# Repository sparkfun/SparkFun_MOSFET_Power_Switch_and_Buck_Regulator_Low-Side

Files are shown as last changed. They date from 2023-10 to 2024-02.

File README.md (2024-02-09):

SparkFun MOSFET Power Switch and Buck Regulator (Low-Side)
========================================

SparkFun MOSFET Power Switch and Buck Regulator (Low-Side) (https://www.sparkfun.com/products/23979)

[*SparkFun MOSFET Power Switch and Buck Regulator (Low-Side) (COM-23979)*](https://www.sparkfun.com/products/23979)

Does your microcontroller need to control a high-voltage item, like a 12V LED strip, while also needing to be powered? Do you want to avoid having multiple power adapters and microcontrollers for your project? The MOSFET Power Switch and Buck Regulator (Low-Side) is one product we needed at SparkFun, so we figured other folks might have the same problem. Power the board with up to 12V and control up to 10A, all while providing a sweet 3.3V to your control board.

The SparkFun MOSFET Power Switch and Buck Regulator (Low-Side) combines two circuits into one board: an LMR14203 buck regulator configured to output 3.3V and an N-channel MOSFET (PSMN7R0-100BS) configured as a low-side switch. A flyback diode is also on the load side for devices with back EMF! Simply pull the CTL pin low to activate the load.

Various connectors (barrel jack, female header, and poke-home) are provided to connect a power supply to a microcontroller of your choice (Arduino, micro-bit, Raspberry Pi’s microcontroller) and load them together. VCC, 3.3V, CTL, and GND are also broken out through 0.1" spaced PTHs for those who prefer to solder. Two LEDs (PWR_LED and ON_LED) indicate when there is 3.3V and whenever power is applied to the load. Jumpers are included on the back to disable the LEDs. A MEAS PTH jumper is also included for those interested in precisely measuring the current consumption of the system.

_**Note:** While the MOSFET is rated to 100A/100V, we don't recommend you go much above 10A as the PCB polygon pours and traces become the limiter._

Repository Contents
-------------------

* **.github/workflows** -  YAML files used for GitHub Actions and GitHub Pages/mkdocs
* * **/Firmware** - Basic example code to control a load with the MOSFET Power Switch and BUck Regulator
* **/Hardware** - Eagle design files (.brd, .sch)
  * **/Production** - Production panel files (.brd)
* **/docs** - Online documentation files for GitHub Pages and mkdocs
  * **/assets** - Folder containing all the file assets used for product documentation
    * **/board_files** - Copy of design files used for product documentation
    * **/component_documentation** - Datasheets and manuals for hardware components
    * **/img** - Images for product documentation
  * **/github** - Files stating how to contribute and filing issues for product
  * **/javascript** - Folder containing custom javascript used for product documentation
  * **/stylesheet** - Folder containing CSS files used forproduct documentation
* **/overrides** - Customization files used for product documentation
  * **/.icons** - Icons used for product documentation
  * **./partials** - Used for product documentation

Documentation
--------------

* **[Fritzing Part](https://github.com/sparkfun/Fritzing_Parts/blob/main/products/23979_sfe_n-channel_mosfet_power_switch_buck_regulator_low-side_transistor.fzpz)**
* **[Hookup Guide](https://docs.sparkfun.com/SparkFun_MOSFET_Power_Switch_and_Buck_Regulator_Low-Side)** - Basic hookup guide for the MOSFET Power Switch and Buck Regulator (Low-Side).

Product Versions
----------------

* [COM-23979](https://www.sparkfun.com/products/23979) - Initial SparkFun release, v1.1
* [SPX-19799](https://www.sparkfun.com/products/19799) - SparkX version

Version History
---------------
* v1.1 - Initial release

License Information
-------------------

This product is _**open source**_! 

Please review the LICENSE.md file for license information. 

If you have any questions or concerns on licensing, please contact technical support on our [SparkFun forums](https://forum.sparkfun.com/viewforum.php?f=152).

Distributed as-is; no warranty is given.

- Your friends at SparkFun.

_<COLLABORATION CREDIT>_

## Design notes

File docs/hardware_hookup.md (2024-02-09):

In this section, we'll go over how to connect the MOSFET Power Switch to your system.

## Upload Code to the Microcontroller

When uploading code to the IoT RedBoard - ESP32, we will connect a USB C cable. When powering the load, we will want to disconnect the USB cable to avoid conflicting voltages.

<div style="text-align: center;">
  <table>
    <tr style="vertical-align:middle;">
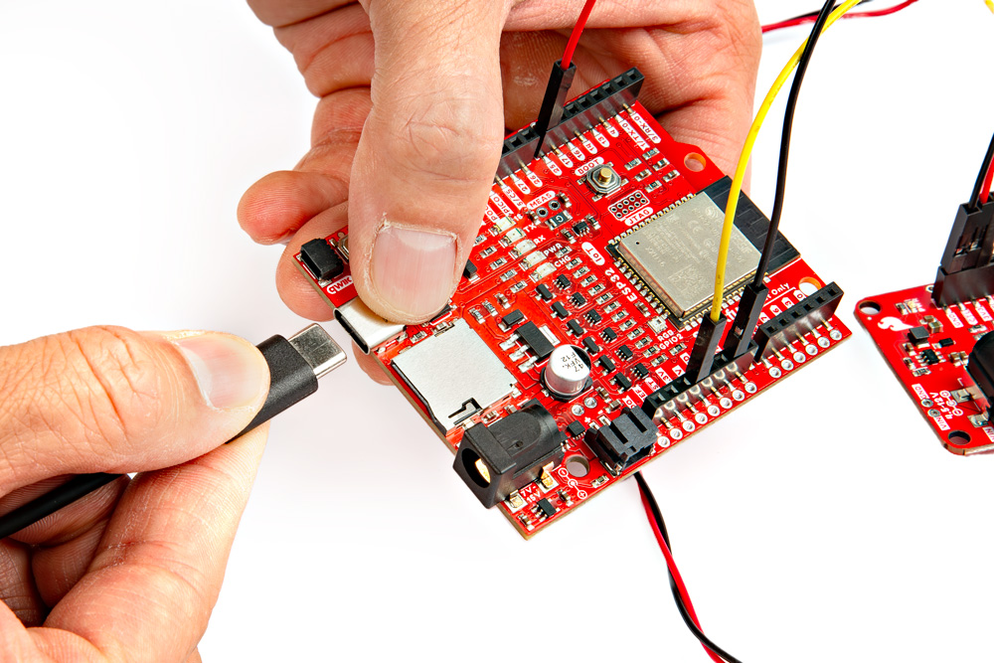
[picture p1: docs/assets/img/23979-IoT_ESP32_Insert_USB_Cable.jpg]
USB Cable Out of USB Connector
     <td style="text-align: center; vertical-align: middle;"></td>
  </table>
</div>

!!! tip
     If necessary, you can disconnect the 3.3V jumper wire connecting the MOSFET Power Switch and Buck Regulator to the IoT RedBoard - ESP32. That way you can power the load with the barrel jack while also debugging code when the USB cable is connected to the IoT RedBoard - ESP32.

### Control

!!! note
    The tutorial focuses on using a microcontroller with Arduino. However, if your microcontroller has a digital or PWM, you can also control the N-channel MOSFET controller as well! You can also use this using a micro:bit with MakeCode or Raspberry Pi's RP2040 microcontroller with MicroPython!

For prototyping or connecting to the control side, we recommend using a 3.3V development board with header pins already soldered to the board. In this case, we used the IoT RedBoard - ESP32. Depending on how you are controlling the load, you may need a digital or PWM pin. Don't forget to connect power and ground. In this case, we will use 3.3V from the output of the buck regulator. Of course, you could also connect the microcontroller or additional devices to the VCC pin as an alternative. Just make sure to choose one when powering your microcontroller or any additional peripheral device.

<div style="text-align: center;">
    <table>
        <tr>
            <th style="text-align: center; border: solid 1px #cccccc;">MOSFET Power Switch
            </th>
            <th style="text-align: center; border: solid 1px #cccccc;">IoT RedBoard - ESP32
            </th>
        </tr>
        <tr>
            <td style="text-align: center; border: solid 1px #cccccc;" bgcolor="#f2dede"><font color="#000000">3V3</font>
            </td>
            <td style="text-align: center; border: solid 1px #cccccc;" bgcolor="#f2dede"><font color="#000000">3.3V</font>
            </td>
        </tr>
        <tr>
            <td style="text-align: center; border: solid 1px #cccccc;" bgcolor="#DDDDDD"><font color="#000000">GND</font>
            </td>
            <td style="text-align: center; border: solid 1px #cccccc;" bgcolor="#DDDDDD"><font color="#000000">GND</font>
            </td>
        </tr>
        <tr>
            <td style="text-align: center; border: solid 1px #cccccc;" bgcolor="#cce5ff"><font color="#000000"><span style="text-decoration:overline">CTL</span></font>
            </td>
            <td style="text-align: center; border: solid 1px #cccccc;" bgcolor="#cce5ff"><font color="#000000">D25</font>
            </td>
        </tr>
    </table>
</div>

Below is a circuit diagram with the MOSFET Power Switch and Buck Regulator Break connecting to the IoT RedBoard - ESP32. Most of the examples will follow this pin connection to control the load. However, there are a few examples that will include additional circuits and a different pin for the control.

<div style="text-align: center;">
  <table>
    <tr style="vertical-align:middle;">
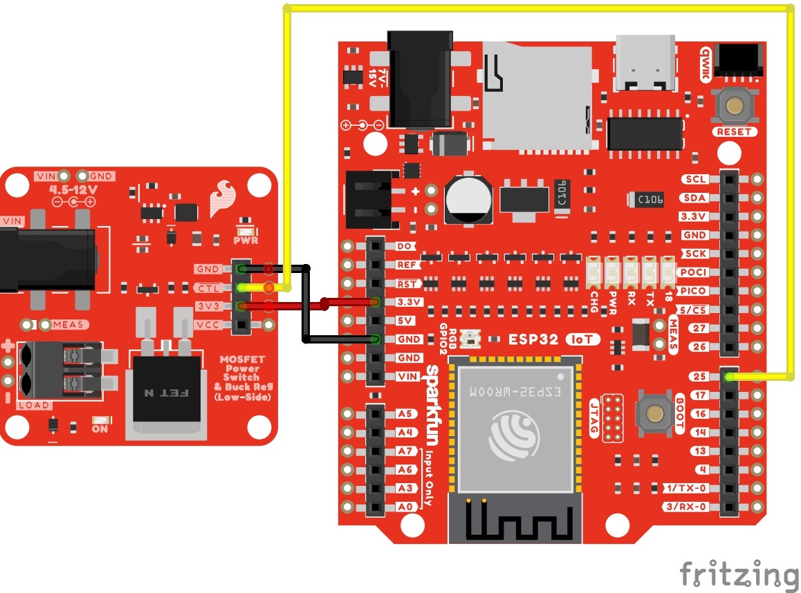
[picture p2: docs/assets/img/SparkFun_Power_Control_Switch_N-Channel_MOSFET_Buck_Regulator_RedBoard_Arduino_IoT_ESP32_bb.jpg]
Power and Control Pin Connected to RedBoard IoT Development Board
     <td style="text-align: center; vertical-align: middle;"></td>
    </tr>
  </table>
</div>

!!! warning
    When powering and programming your Arduino, make sure to disconnect power between the MOSFET Power Switch and Arduino to avoid conflicting voltages. Of course you could use a [Schottky diode for protection](https://learn.sparkfun.com/tutorials/diodes#diode-applications). The caveat is that you will just have a slight voltage drop.

### Load

Connect a high voltage device of your choice (e.g. DC motor, solenoid, 12V LED) to the load side (VCC to &plus; and GND to &minus;). You will need a ball point pen to push down on each poke-home connector's tab. A [mini screwdriver](https://www.sparkfun.com/products/9146) (Phillips or flat head) will also work as well.  As you are pressing down on the tab, insert a [stripped wire](https://learn.sparkfun.com/tutorials/working-with-wire/how-to-strip-a-wire) or jumper wire pin into the socket. Repeat for the other connection.

<div style="text-align: center;">
  <table>
    <tr style="vertical-align:middle;">
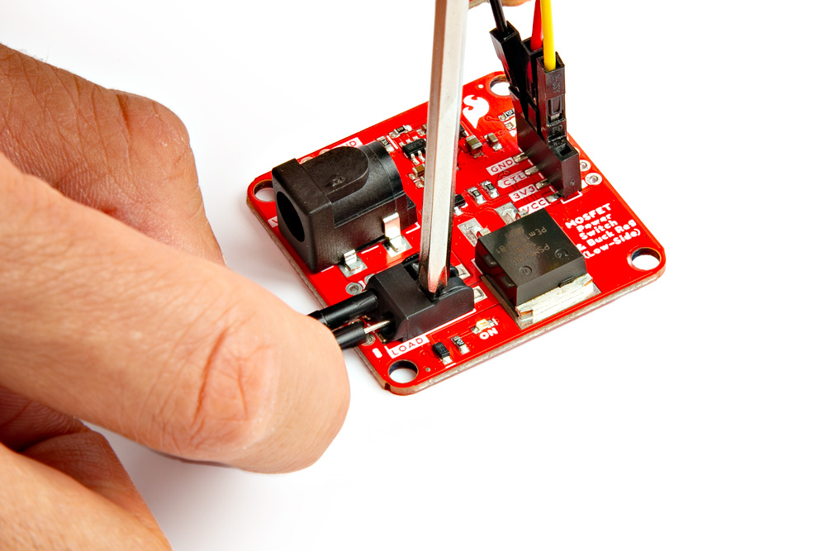
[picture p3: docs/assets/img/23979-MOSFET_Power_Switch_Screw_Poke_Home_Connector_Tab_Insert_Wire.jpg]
Mini Screwdriver Pushing Down on Poke-Home Connector Tab and Wire Being Inserted
     <td style="text-align: center; vertical-align: middle;"></td>
    </tr>
  </table>
</div>

Below are a few examples. The squirrel cage blower we just inserted the Poke-Home conenctor since the wires were stripped. For the latching solenoid, we used M/M jumper wires between the 2-pin connector and the Poke-Home connector. We used part of a 12V LED strip rather than a full strip.

<div style="text-align: center;">
  <table>
    <tr style="vertical-align:middle;">
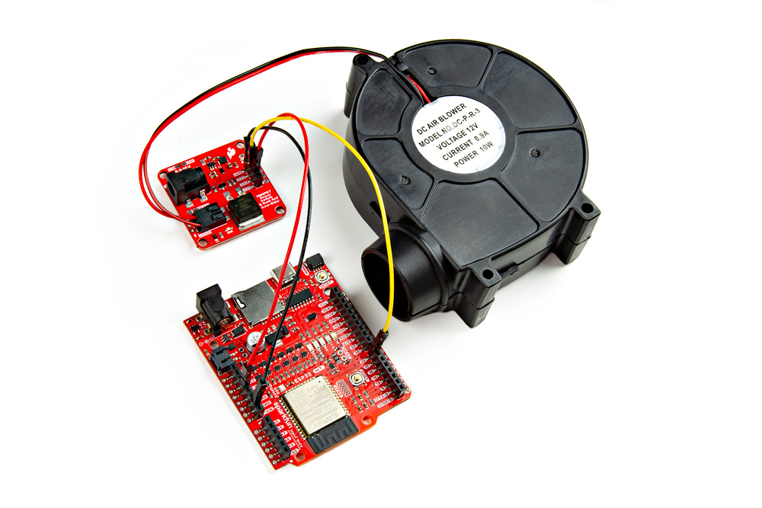
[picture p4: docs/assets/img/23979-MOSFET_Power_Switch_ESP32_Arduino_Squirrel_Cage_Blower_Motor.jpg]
DC Motor to MOSFET Power Switch
     <td style="text-align: center; vertical-align: middle;"></td>
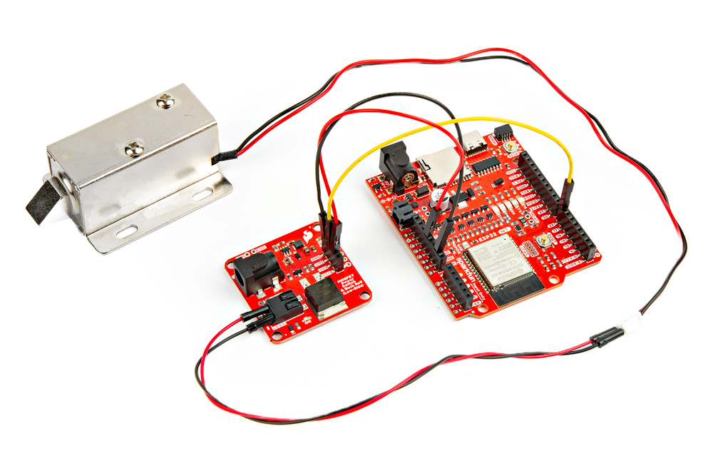
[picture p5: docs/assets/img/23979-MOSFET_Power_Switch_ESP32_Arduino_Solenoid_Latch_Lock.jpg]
Solenoid to MOSFET Power Switch
     <td style="text-align: center; vertical-align: middle;"></td>
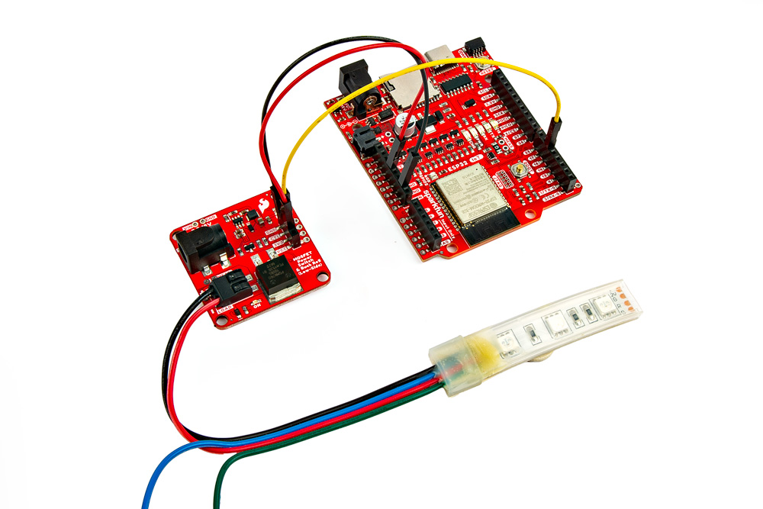
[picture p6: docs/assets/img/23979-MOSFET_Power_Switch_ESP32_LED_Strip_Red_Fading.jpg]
12V LED Strip to MOSFET Power Switch
     <td style="text-align: center; vertical-align: middle;"></td>
    </tr>
  </table>
</div>

!!! tip
    Worried about the M/M jumper wire's pins when inserting the Poke-Home connector? There are other [M/M jumper wires available](https://www.sparkfun.com/products/11026). These are lower cost and  so you do not have to worry about damaging your premium jumper wires. These were used with the latching solenoid's 2-pin connector.

### Input Voltage

Grab a compatible wall adapter that is within the recommended voltage range for your project. Make sure that the barrel jack's output is a center-positive. Then insert it into the barrel jack connector.

<div style="text-align: center;">
  <table>
    <tr style="vertical-align:middle;">
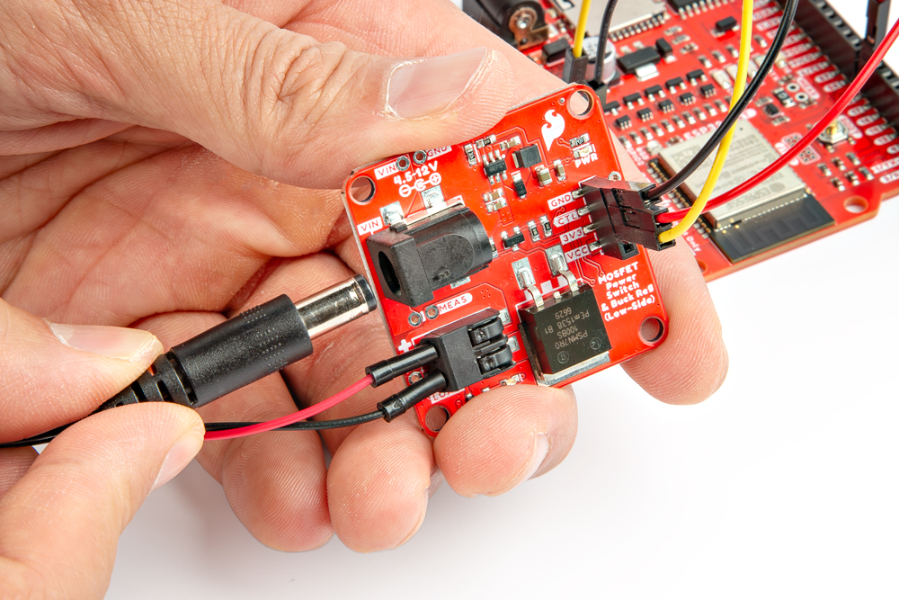
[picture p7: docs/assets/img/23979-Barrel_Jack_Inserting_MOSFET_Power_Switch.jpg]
Wall Adapter Connected to Barrel Jack
     <td style="text-align: center; vertical-align: middle;"></td>
    </tr>
  </table>
</div>

### Connecting to the PTHs

For users that prefer to use the PTHs, we recommending soldering to the connection. You can choose between a combination of [header pins and jumper wires](https://learn.sparkfun.com/tutorials/how-to-solder-through-hole-soldering/all), or [stripping wire and soldering the wire](https://learn.sparkfun.com/tutorials/working-with-wire/all) directly to the board.

<div class="grid cards hide col-4" markdown>

-   <a href="https://learn.sparkfun.com/tutorials/how-to-solder-through-hole-soldering/all">
      <figure markdown>
        How to Solder: Through Hole Soldering
      </figure>
    </a>

    ---

    <a href="https://learn.sparkfun.com/tutorials/how-to-solder-through-hole-soldering/all">
      <b>How to Solder: Through Hole Soldering</b>
    </a>
<!-- ----------WHITE SPACE BETWEEN GRID CARDS---------- -->
-   <a href="https://learn.sparkfun.com/tutorials/working-with-wire/all">
      <figure markdown>
        Working with Wire
      </figure>
    </a>

    ---

    <a href="https://learn.sparkfun.com/tutorials/working-with-wire/all">
      <b>Working with Wire</b>
    </a>
<!-- ----------WHITE SPACE BETWEEN GRID CARDS---------- -->
</div>

!!! tip
    The PTHs are connected to large polygon pours and traces. You may need a larger soldering iron tip, increase the soldering station's temperature, some flux, or leave the soldering tip a little longer in order for the solder to flow better.

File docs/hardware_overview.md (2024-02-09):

In this section, we will highlight the features of the N-channel MOSFET Power Switch and Buck Regulator (Low-Side). For more information about the LMR14203 3.3V buck regulator or PSMN7R0-100BS N-channel MOSFET, make sure to check out the datasheets that are linked in the [Resources section](../resources).

<div style="text-align: center;">
  <table>
    <tr style="vertical-align:middle;">
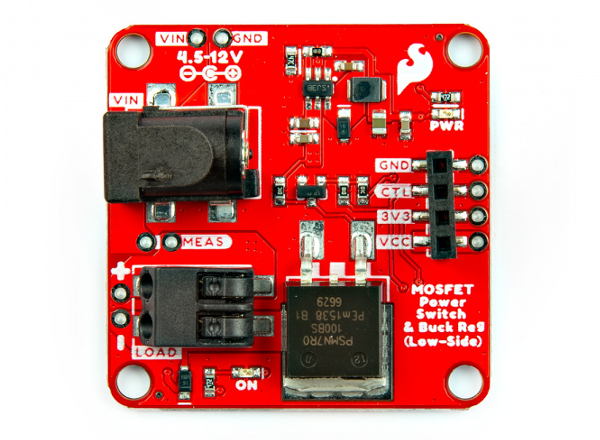
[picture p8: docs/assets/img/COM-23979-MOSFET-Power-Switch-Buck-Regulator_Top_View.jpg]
MOSFET Power Switch Top
     <td style="text-align: center; vertical-align: middle;"></td>
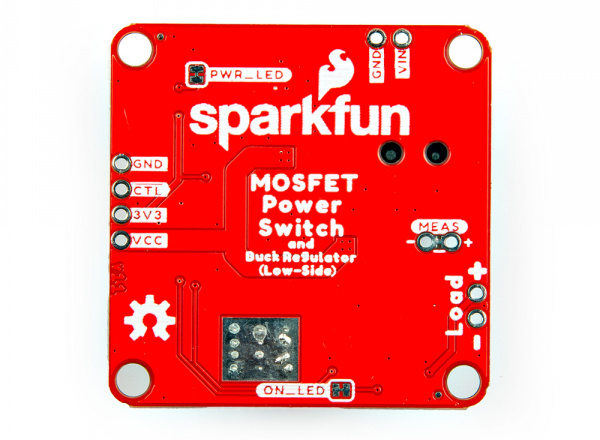
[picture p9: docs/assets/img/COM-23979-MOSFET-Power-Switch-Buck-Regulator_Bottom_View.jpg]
MOSFET Power Switch Bottom
     <td style="text-align: center; vertical-align: middle;"></td>
    </tr>
    <tr style="vertical-align:middle;">
     <td style="text-align: center; vertical-align: middle;"><i>Top View</i>
     </td>
     <td style="text-align: center; vertical-align: middle;"><i>Bottom View</i>
     </td>
    </tr>
  </table>
</div>

### N-Channel MOSFET

The N-channel MOSFET is configured as a low-side switch. On the back of the board, there is a ground plane to aid in heat dissipation. At 12V, 3A the board stays cool (40 &degC;) under a continuous load. At 12V, 8.5A with shorter bursts of current (i.e. 5-10 seconds per burst, max current), the board gets toasty (80&degC;). You will want to avoid touching the board since it will burn your finger.

<div style="text-align: center;">
  <table>
    <tr style="vertical-align:middle;">
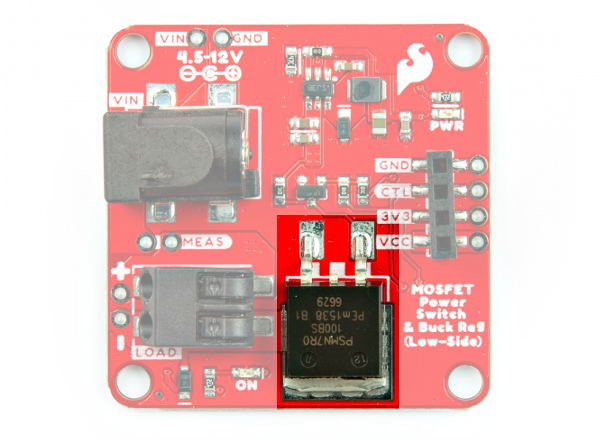
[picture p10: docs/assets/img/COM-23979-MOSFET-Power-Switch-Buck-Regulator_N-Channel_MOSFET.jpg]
N-Channel MOSFET Highlighted
     <td style="text-align: center; vertical-align: middle;"></td>
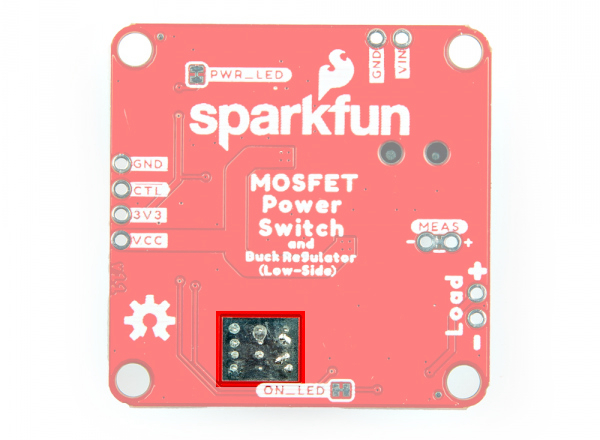
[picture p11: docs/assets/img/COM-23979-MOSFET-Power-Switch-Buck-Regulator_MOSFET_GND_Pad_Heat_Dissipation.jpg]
Ground Plane Under MOSFET Highlighted for Heat Dissipation
     <td style="text-align: center; vertical-align: middle;"></td>
    </tr>
    <tr style="vertical-align:middle;">
     <td style="text-align: center; vertical-align: middle;"><i>N-Channel MOSFET</i>
     </td>
     <td style="text-align: center; vertical-align: middle;"><i>Ground Plane Under MOSFET for Heat Dissipation</i>
     </td>
    </tr>
  </table>
</div>

### Input Voltage

There are two options to connect to the input voltage:

* **Barrel Jack** &mdash; For users with a wall adapter, you could use a 5.5mm x 2.1mm center positive, barrel jack with the recommended input voltage. This is for users that want to easily connect the power supply without the need to solder. Make sure to check the specifications of your wall adapter before connecting since some power supplies have a different polarity.
* **PTHs** &mdash; There is also a pair of pads beside the barrel jack to connect to the input voltage (**VIN**) and ground (**GND**). The PTHs are for users that want a more permanent connection and require a smaller profile by soldering wires directly to the PTH. We recommend connecting power from your power supply to this VIN PTH rather than the one by the 1x4 header. The polygon pours connected to the PTH are thicker and can handle the power as opposed to the VCC pin by the 1x4 header.

These connections are broken out as follows:

* **VIN** &mdash; The recommended input voltage is between **4.5V** and **12V**.
* **GND** &mdash; Common ground or 0V.

<div style="text-align: center;">
  <table>
    <tr style="vertical-align:middle;">
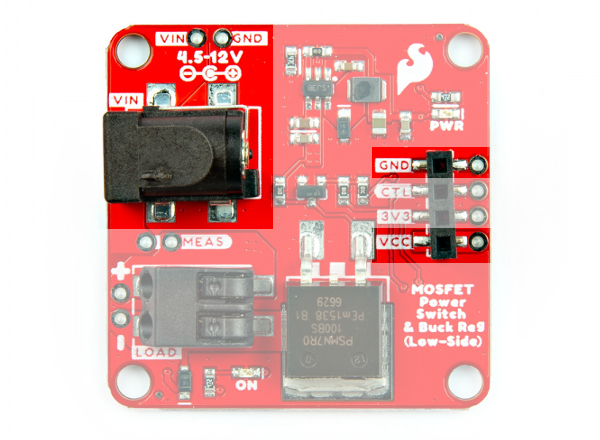
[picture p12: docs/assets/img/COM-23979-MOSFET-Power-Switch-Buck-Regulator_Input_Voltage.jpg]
Input Voltage Options Highlighted
     <td style="text-align: center; vertical-align: middle;"></td>
    </tr>
    <tr style="vertical-align:middle;">
     <td style="text-align: center; vertical-align: middle;"><i>Input Voltage Options Highlighted
         </i>
     </td>
    </tr>
  </table>
</div>

### 3.3V Regulator Output Voltage

Voltage from the input is brought down to 3.3V/300mA with the buck regulator. This is intended to connect to a microcontroller's 3.3V pin using either the 1x4 header and the PTHs.

<div style="text-align: center;">
  <table>
    <tr style="vertical-align:middle;">
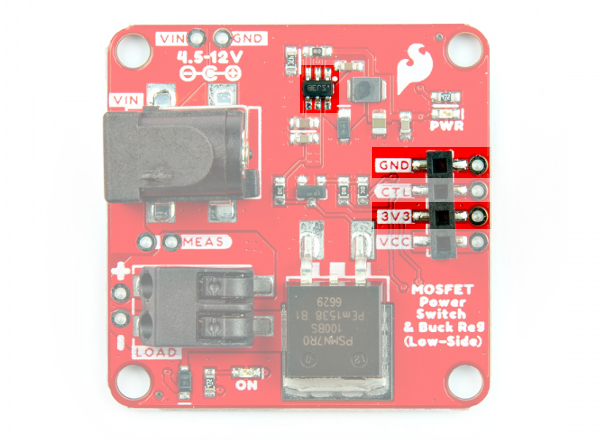
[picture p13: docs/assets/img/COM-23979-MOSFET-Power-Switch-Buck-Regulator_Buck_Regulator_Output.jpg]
     <td style="text-align: center; vertical-align: middle;"></td>
    </tr>
    <tr style="vertical-align:middle;">
     <td style="text-align: center; vertical-align: middle;"><i>Output Voltage Highlighted
         </i>
     </td>
    </tr>
  </table>
</div>

### 1x4 Header Connections

On the side of the board, there are two options to connect to ground, control pin, output 3.3V voltage, and input voltage,

* **1x4 female header** &mdash; Users that have jumper wires with male pins can easily connect to the female headers.
* **PTHs** &mdash; For users that require a more secure connection like the input voltage side, you can also solder to the PTHs as well. As explained earlier, the traces connecting to the VCC on this side is not as big as the one by VIN by the barrel jack.

These connections are broken out as follows:

* **GND** &mdash; Common ground or 0V.
* **<span style="text-decoration:overline">CTL</span>** &mdash; Short for control, this pin is connected to the N-channel MOSFET's gate pin and it is active low. There is a [pull-up resistor](https://learn.sparkfun.com/tutorials/pull-up-resistors/all) connected to this pin. Users can connect to a jumper wire from this pin to GND to turn on the MOSFET and provide power to the load. Of course, this board was designed to connect to a microcontroller so it can be connected to a digital or PWM pin. Toggling the control pin with the digital pin will turn on and off MOSFET. Using a PWM pin will give you more flexibility to turn on, off, or partially on the load.  
* **3V3** &mdash; 3.3V output from the buck regulator. This is intended to connect to a microcontroller's 3.3V pin.
* **VCC** &mdash; This pin is connected to the MEAS jumper and VIN. The trace connecting to the pin on the control side is smaller than the polygon pour for VIN. Users can also connect the microcontroller's input voltage to this pin as an alternative to using the 3V3 if their system requires. Just make sure to choose either the 3V3 or VCC to power the microcontroller. Of course, users can also power additional devices on this pin as well.

<div style="text-align: center;">
  <table>
    <tr style="vertical-align:middle;">
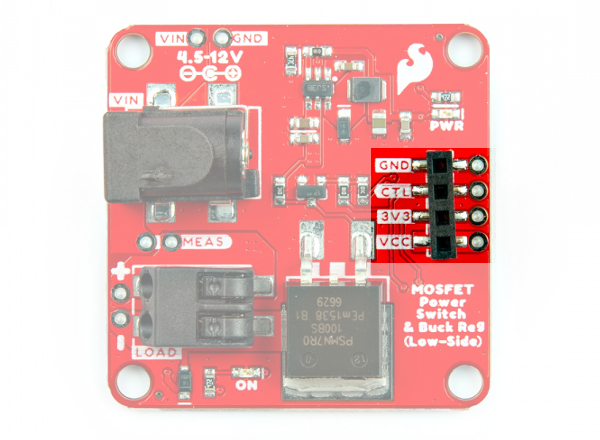
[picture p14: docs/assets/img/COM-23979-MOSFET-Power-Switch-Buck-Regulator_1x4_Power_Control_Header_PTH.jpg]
Control Side Highlighted
     <td style="text-align: center; vertical-align: middle;"></td>
    </tr>
    <tr style="vertical-align:middle;">
     <td style="text-align: center; vertical-align: middle;"><i>1x4 Header Highlighted
         </i>
     </td>
    </tr>
  </table>
</div>

### Load Side

There are two options to connect to the output load side.

* **Poke-Home Connectors** &mdash; For users that have a stripped wire or jumper wire pins, you can use a ballpoint pen to press down on the tab of the connector to insert a stripped wire or pin into the connector. You can also use a mini screwdriver (Phillips or flat head)
* **PTHs** &mdash; For users that want a permanent connection, you can solder your load directly to the PTHs.

The N-channel MOSFET is configured as a low-side switch: the load is connected to the N-channel MOSFET's drain pin, while the source is connected to ground

The load side connections are broken out as follows:

* **VCC** (or &plus;) &mdash; This pin is for connecting the load's input voltage to the VCC pin.
* **LOAD** (or &minus;) &mdash; This pin is intended for connecting the load's ground to the LOAD pin.

<div style="text-align: center;">
  <table>
    <tr style="vertical-align:middle;">
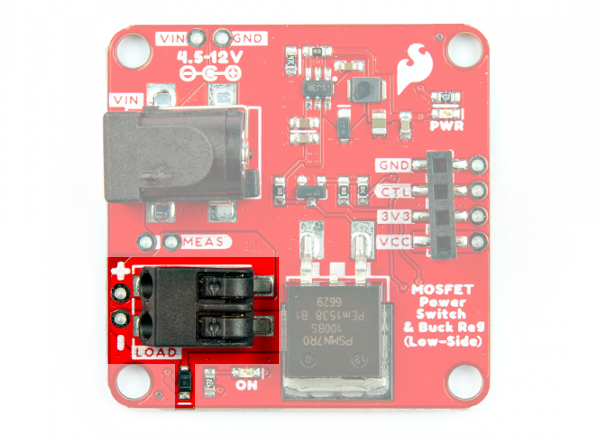
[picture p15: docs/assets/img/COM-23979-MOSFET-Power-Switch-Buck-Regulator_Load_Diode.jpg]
Load Side Highlighted
     <td style="text-align: center; vertical-align: middle;"></td>
    </tr>
    <tr style="vertical-align:middle;">
     <td style="text-align: center; vertical-align: middle;"><i>Load Side Highlighted
         </i>
     </td>
    </tr>
  </table>
</div>

!!! note
    There is also a flyback diode connected to the load side! This component is for loads with motors. When the motor is spinning and suddenly turned off, the magnetic field inside it collapses, generating a voltage spike. This can damage the transistor. These voltage spikes can also happen with solenoids. The image below (taken from [Pete](https://github.com/lewispg228)'s camera!) shows an [oscilloscope](https://learn.sparkfun.com/tutorials/how-to-use-an-oscilloscope/all) measuring the nasty voltage spike as soon as the 12V latching solenoid (without a flyback diode) is turned off.

    <div style="text-align: center;">
      <table>
        <tr style="vertical-align:middle;">
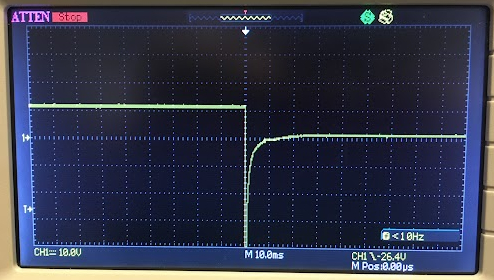
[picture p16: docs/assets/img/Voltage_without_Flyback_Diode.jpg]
Voltage without Flyback Diode
         <td style="text-align: center; vertical-align: middle;"></td>
        </tr>
        <tr style="vertical-align:middle;">
         <td style="text-align: center; vertical-align: middle;"><i>Voltage without Flyback Diode
             </i>
         </td>
        </tr>
      </table>
    </div>

    To prevent voltage spikes, we use a "[flyback diode](https://learn.sparkfun.com/tutorials/diodes#diode-applications)," which suppresses the voltage spike. As seen below the voltage is not as dangerous for our N-channel MOSFET.

    <div style="text-align: center;">
      <table>
        <tr style="vertical-align:middle;">
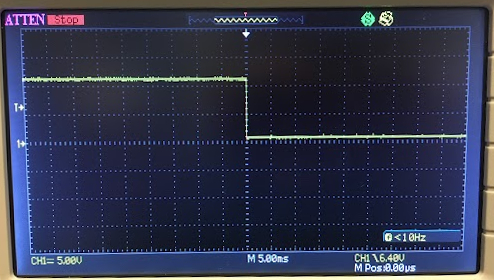
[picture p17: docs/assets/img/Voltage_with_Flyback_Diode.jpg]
Voltage without Flyback Diode
         <td style="text-align: center; vertical-align: middle;"></td>
        </tr>
        <tr style="vertical-align:middle;">
         <td style="text-align: center; vertical-align: middle;"><i>Voltage with Flyback Diode
             </i>
         </td>
        </tr>
      </table>
    </div>

### LEDs

There are two LEDs on the board.

* **PWR** &mdash; The power LED lights up when there is power on the output of the 3.3V buck regulator. This LED can be disabled by cutting the trace on the **PWR_LED** jumper.
* **ON** &mdash; The ON LED lights up when the control pin is pulled low indicating that there is power applied to the load. This LED can be disabled by cutting the trace on the **ON_LED** jumper.

<div style="text-align: center;">
  <table>
    <tr style="vertical-align:middle;">
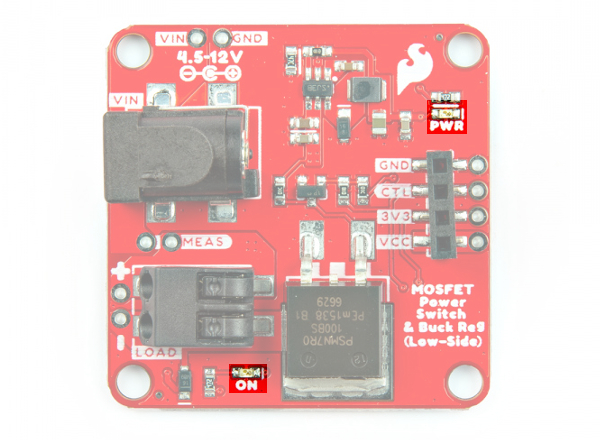
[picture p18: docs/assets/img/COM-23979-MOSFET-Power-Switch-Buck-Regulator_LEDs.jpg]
LEDs Highlighted
     <td style="text-align: center; vertical-align: middle;">
     </td>
    </tr>
    <tr style="vertical-align:middle;">
     <td style="text-align: center; vertical-align: middle;"><i>LEDs Highlighted
         </i>
     </td>
    </tr>
  </table>
</div>

### Jumpers

There are a few jumper pads available on the bottom of the board. For more information on modifying the jumpers, check out our [tutorial on working with jumper pads and PCB traces](https://learn.sparkfun.com/tutorials/how-to-work-with-jumper-pads-and-pcb-traces).

* **PWR_LED** &mdash; By default, this jumper is closed. This is connected to the **PWR** LED and indicates when there is power. Cut this trace to disable the power LED that is connected to 3.3V.
* **MEAS** &mdash; To enable measurements and determine how much current your system is pulling, we've added a NC (normally closed) jumper between the two MEAS PTH pins. By cutting this jumper, the voltage connecting to the 3.3V voltage regulator's input is interrupted. Soldering in male jumper pins or wires into the accompanying holes will give you the ability to insert a current meter and precisely monitor how much current your application is consuming.
* **ON_LED** &mdash; By default, this jumper is closed. This is connected to the **ON** LED. This LED indicates when the control pin is pulled low and when there is power applied to the load. Cut this trace to disable the **ON** LED that is connected to the control pin.

<div style="text-align: center;">
  <table>
    <tr style="vertical-align:middle;">
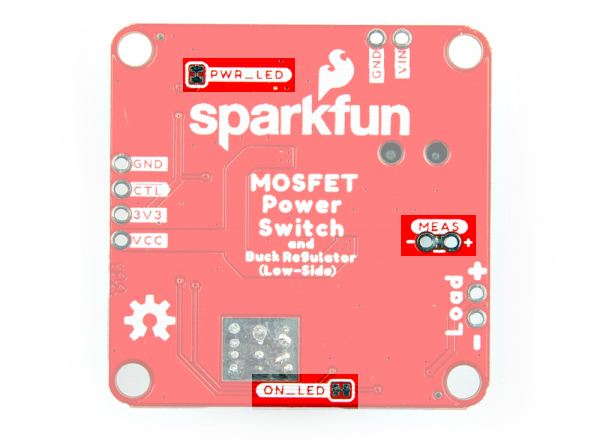
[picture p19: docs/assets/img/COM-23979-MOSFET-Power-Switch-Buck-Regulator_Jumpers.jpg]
Jumpers Highlighted
     <td style="text-align: center; vertical-align: middle;"></td>
    </tr>
    <tr style="vertical-align:middle;">
     <td style="text-align: center; vertical-align: middle;"><i>Jumpers Highlighted
         </i>
     </td>
    </tr>
  </table>
</div>

### Board Dimensions

The board is 1.50" x 1.50" (38.1mm x 38.1mm), which is slightly bigger than a typical 1.0"x1.0" Qwiic sized board. There are 4x mounting holes by each corner of the board.

<div style="text-align: center;">
  <table>
    <tr style="vertical-align:middle;">
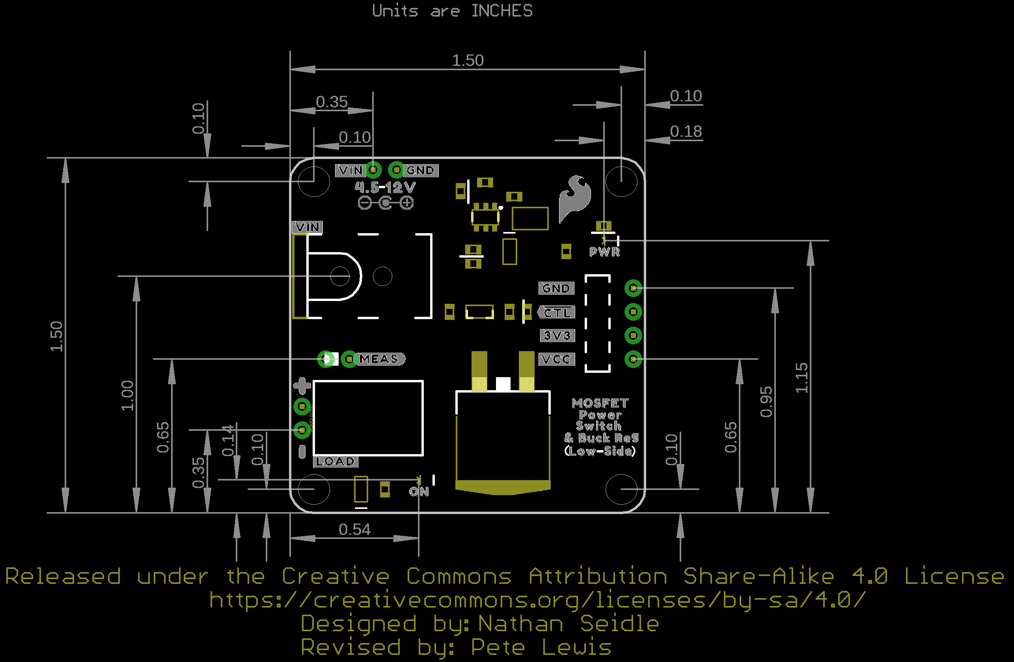
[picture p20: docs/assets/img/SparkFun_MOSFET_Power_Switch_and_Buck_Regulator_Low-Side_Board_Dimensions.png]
Board Dimensions
     <td style="text-align: center; vertical-align: middle;"></td>
    </tr>
    <tr style="vertical-align:middle;">
     <td style="text-align: center; vertical-align: middle;"><i>Board Dimensions
         </i>
     </td>
    </tr>
  </table>
</div>

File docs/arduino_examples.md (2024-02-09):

!!! arduino
    This example assumes you are using the latest version of the Arduino IDE on your desktop. If this is your first time using the Arduino IDE or board add-on, please review the following tutorials.

    - [Installing the Arduino IDE](https://learn.sparkfun.com/tutorials/installing-arduino-ide)
    - [Installing Board Definitions in the Arduino IDE](https://learn.sparkfun.com/tutorials/installing-board-definitions-in-the-arduino-ide)

    If you've never connected an CH340 device to your computer before, you may need to install drivers for the USB-to-serial converter. Check out our section on "[How to Install CH340 Drivers](https://learn.sparkfun.com/tutorials/sparkfun-serial-basic-ch340c-hookup-guide#drivers-if-you-need-them)" for help with the installation.

You will need either a microcontroller's digital or PWM pin to control the N-channel MOSFET Power Switch. Let's check out a few of the examples below to get started!

### Example 1: Switching a Load

In this example, we will turn on and off a load using the N-channel MOSFET every few seconds. The load can be a solenoid, DC motor, or a 12V LED.

#### Parts Needed

Grab the following quantities of each part listed to build this circuit:

* 1x [SparkFun IoT RedBoard - ESP32 Development Board](https://www.sparkfun.com/products/19177)
* 1x [USB-C Cable](https://www.sparkfun.com/products/15092)
* 3x [SparkFun MOSFET Power Switch and Buck Regulator (Low-Side)](https://www.sparkfun.com/products/23979)
* 1x [SparkFun Mini Screwdriver](https://www.sparkfun.com/products/9146)
* 3x [M/M Jumper Wires](https://www.sparkfun.com/products/8431)
* 1x [Squirrel Cage Blower (12V)](https://www.sparkfun.com/products/11270)
* 1x Ping Pong Ball
* 1x [12V Wall Adapter Power Supply](https://www.sparkfun.com/products/15313)

#### Hardware Hookup

You will need to connect everything as explained earlier. For this particular example, we will use a squirrel cage blower with a motor as shown in the circuit diagram below. Of course, we are using a generic motor in the circuit diagram to represent the squirrel cage blower.

<div style="text-align: center;">
  <table>
    <tr style="vertical-align:middle;">
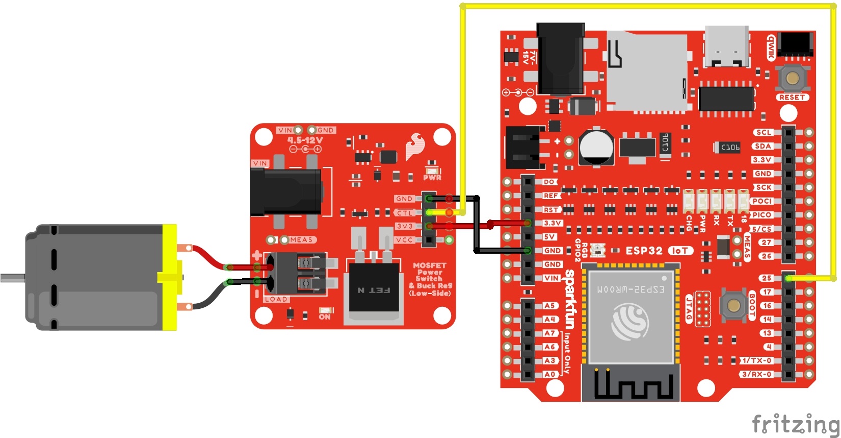
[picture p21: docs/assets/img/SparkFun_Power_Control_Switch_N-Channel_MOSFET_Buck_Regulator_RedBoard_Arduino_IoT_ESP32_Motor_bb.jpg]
DC Motor to MOSFET Power Switch
     <td style="text-align: center; vertical-align: middle;"></td>
    </tr>
  </table>
</div>

Your setup should look similar to the image below without the power supply.

<div style="text-align: center;">
  <table>
    <tr style="vertical-align:middle;">
     <td style="text-align: center; vertical-align: middle;"><a href="../assets/img/23979-MOSFET_Power_Switch_ESP32_Arduino_Squirrel_Cage_Blower_Motor.jpg">DC Motor to MOSFET Power Switch</a></td>
    </tr>
  </table>
</div>

#### Upload Code

To upload code, insert the USB cable into the IoT RedBoard - ESP32.

!!! note
    This example is similar to the built-in Arduino example. From the menu, select the following: **File** > **Examples** > **01.Basics** > **Blink**. You will need to modify the macro (`LED_BUILTIN`) with a digital pin for your microcontroller. Note that the logic is reversed due to the transistor.

Copy the following code and paste it in the Arduino IDE. If you have not already, select your Board (in this case, the **SparkFun ESP32 IoT RedBoard**), and associated COM port. Then hit the upload button.

``` c
/******************************************************************************
  Example 1: Switching a Load
  Modified By: Ho Yun "Bobby" Chan
  SparkFun Electronics
  Date: October 27th, 2023
  License: MIT. See license file for more information but you can
  basically do whatever you want with this code.

  This example is based on Arduino's blink example. It has been modified
  so that it can be used for the SparkFun IoT RedBoard - ESP32 but it can be
  used with any Arduino that has a digital pin. The load (solenoid, DC motor,
  or 12V LED) will toggle on and off every 5 seconds.

  Users can also open the Serial Monitor at 115200 to check on
  the status of the load for debugging.

  Feel like supporting open source hardware?
  Buy a board or component from SparkFun!

      SparkFun IoT RedBoard - ESP32 Development Board:            https://www.sparkfun.com/products/19177
      SparkFun MOSFET Power Switch and Buck Regulator (Low-Side): https://www.sparkfun.com/products/23979
      Solenoid - 12V (Latch / Lock):                              https://www.sparkfun.com/products/15324
      Hobby Motor - Gear:                                         https://www.sparkfun.com/products/11696
      Blower - Squirrel Cage (12V):                               https://www.sparkfun.com/products/11270
      12V LED RGB Strip - Bare (1m):                              https://www.sparkfun.com/products/12021
      Wall Adapter 12V/600mA, (Barrel Jack):                      https://www.sparkfun.com/products/15313

  Distributed as-is; no warranty is given.
******************************************************************************/

//define a pin for the load, you'll need to adjust this
//depending on the microcontroller that you using
const int loadPin = 25;

// the setup function runs once when you press reset or power the board
void setup() {

  //Initialize Serial for Debugging if there is no built-in LED
  Serial.begin(115200);
  Serial.println("Toggling a Load!");

  // initialize digital pin as an output.
  pinMode(loadPin, OUTPUT);
  digitalWrite(loadPin, HIGH);  // turn the LOAD off (HIGH is the voltage level)
  Serial.println("OFF");

}  //END SETUP

// the loop function runs over and over again forever
void loop() {

  digitalWrite(loadPin, LOW);  // turn the LOAD ON (LOW is the voltage level)
  Serial.println("ON");
  delay(5000);  // wait for a few seconds

  digitalWrite(loadPin, HIGH);  // turn the LOAD OFF by making the voltage HIGH
  Serial.println("OFF");
  delay(5000);  // wait for a few seconds

}  //END LOOP

```

#### What You Should See

Once the code has uploaded, Once the code has uploaded, disconnect the USB cable from the IoT RedBoard - ESP32. Then insert the barrel jack from a power supply to the MOSFET Power Switch and Buck Regulator's barrel jack connector. In this case, we used a 12V wall adapter power supply.

The load will be powered on for 5 seconds before turning back off for another 5 seconds. Compared to the original blink example, the delay is longer to allow enough time for the load to turn on. This will loop forever until you remove power. If necessary, disconnect the 3.3V jumper wire from the IoT RedBoard - ESP32, reconnect the USB cable, and open the [Arduino Serial Monitor](https://learn.sparkfun.com/tutorials/terminal-basics/arduino-serial-monitor-windows-mac-linux) at **115200** baud for debugging purposes.

<div style="text-align: center;">
  <table>
    <tr style="vertical-align:middle;">
     <td style="text-align: center; vertical-align: middle;"><a href="../assets/img/23979-MOSFET_Power_Switch_ESP32_Arduino_Squirrel_Cage_Blower_Motor_levitating_Ping_Pong_Ball.gif">Squirrel Cage Blower</a></td>
    </tr>
  </table>
</div>

Try adjusting the delay or even adding a Qwiic sensor with some code to trigger a load!

### Example 2: Toggling a Load with a Button

In this example, we will turn on and off a load using the N-channel MOSFET with a button press. The load can be a solenoid, DC motor, or a 12V LED.

#### Parts Needed

Grab the following quantities of each part listed to build this circuit:

* 1x [SparkFun IoT RedBoard - ESP32 Development Board](https://www.sparkfun.com/products/19177)
* 1x [USB-C Cable](https://www.sparkfun.com/products/15092)
* 3x [SparkFun MOSFET Power Switch and Buck Regulator (Low-Side)](https://www.sparkfun.com/products/23979)
* 1x [SparkFun Mini Screwdriver](https://www.sparkfun.com/products/9146)
* 7x [M/M Jumper Wires](https://www.sparkfun.com/products/8431)
* 1x [Mini Breadboard](https://www.sparkfun.com/products/12045)
* 1x [Momentary Push Button](https://www.sparkfun.com/products/14460)
* 1x [Latching Solenoid (12V)](https://www.sparkfun.com/products/15324)
* 1x [12V Wall Adapter Power Supply](https://www.sparkfun.com/products/15313)

#### Hardware Hookup

You will need to connect everything as explained earlier (with the exception of the momentary push button). For this particular example, we will use a latching solenoid and add a momentary pushbutton as shown in the circuit diagram below.

<div style="text-align: center;">
  <table>
    <tr style="vertical-align:middle;">
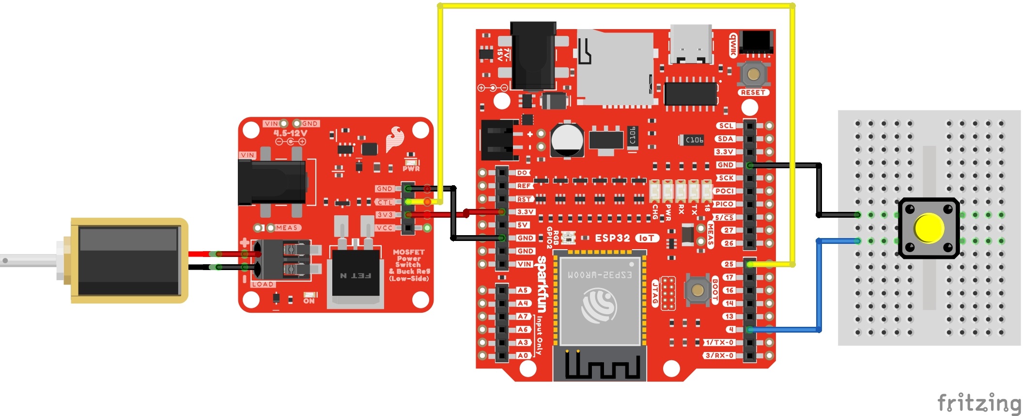
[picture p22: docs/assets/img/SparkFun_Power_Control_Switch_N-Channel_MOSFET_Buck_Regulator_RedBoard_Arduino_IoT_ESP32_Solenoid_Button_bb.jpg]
Solenoid, MOSFET Power Switch, Button, IoT RedBoard - ESP32 Connected
     <td style="text-align: center; vertical-align: middle;"></td>
    </tr>
  </table>
</div>

Your setup should look similar to the image below without the power supply.

<div style="text-align: center;">
  <table>
    <tr style="vertical-align:middle;">
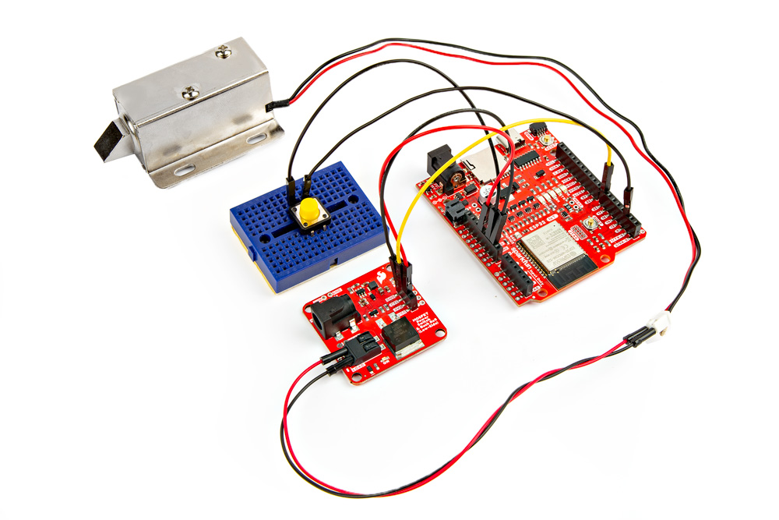
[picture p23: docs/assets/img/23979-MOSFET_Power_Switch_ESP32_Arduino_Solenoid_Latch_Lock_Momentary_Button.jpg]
DC Motor to MOSFET Power Switch
     <td style="text-align: center; vertical-align: middle;"></td>
    </tr>
  </table>
</div>

#### Upload Code

To upload code, insert the USB cable into the IoT RedBoard - ESP32.

Copy the following code and paste it in the Arduino IDE. If you have not already, select your Board (in this case, the **SparkFun ESP32 IoT RedBoard**), and associated COM port. Then hit the upload button.

``` c
/******************************************************************************
  Example 2: Toggling a Load with a Button
  Written By: Ho Yun "Bobby" Chan
  SparkFun Electronics
  Date: October 27th, 2023
  License: MIT. See license file for more information but you can
  basically do whatever you want with this code.

  This example toggles the load (solenoid, DC motor, or 12V LED)
  based on a button press. The status LED will light up at the
  same time. This example checks to see if the momentary button
  is still being pressed and will only toggle the load when the
  button after releasing and pressing down on the button again.

  The example was tested on the SparkFun IoT RedBoard - ESP32.
  However, it can be used with any Arduino that has a digital pin.
  Users can also open the Serial Monitor at 115200 to check on
  the status of the button for debugging.

  Feel like supporting open source hardware?
  Buy a board or component from SparkFun!

      SparkFun MOSFET Power Switch and Buck Regulator (Low-Side): https://www.sparkfun.com/products/23979
      SparkFun IoT RedBoard - ESP32 Development Board:            https://www.sparkfun.com/products/19177
      Solenoid - 12V (Latch / Lock):                              https://www.sparkfun.com/products/15324
      Hobby Motor - Gear:                                         https://www.sparkfun.com/products/11696
      Blower - Squirrel Cage (12V):                               https://www.sparkfun.com/products/11270
      12V LED RGB Strip - Bare (1m):                              https://www.sparkfun.com/products/12021
      Wall Adapter 12V/600mA, (Barrel Jack):                      https://www.sparkfun.com/products/15313

  Distributed as-is; no warranty is given.
******************************************************************************/

// pushbutton 1 pin
const int button1Pin = 4;
boolean button1State = false;
boolean prevbutton1State = false;
boolean currentbutton1State = false;

//define a pin for the load, you'll need to adjust this
//depending on the microcontroller that you using
const int loadPin = 25;
boolean mode = false;  //mode to toggle load, set to off at the start

const int ledPin = 18;  // built-in LED pin for IoT RedBoard - ESP32
                        /*Note: Users can also use the macro LED_BUILTIN. Just make sure to comment the line above
                        and replace "ledPIN" with "LEDBUILTIN"*/

void setup() {

  //Initialize Serial for Debugging if there is no built-in LED
  Serial.begin(115200);
  Serial.println("Toggling a Load with a Button!");

  // Set up the pushbutton pin to be an input with a pull-up resistor:
  pinMode(button1Pin, INPUT_PULLUP);

  // Set up the load pin to be an output and turn it off:
  pinMode(loadPin, OUTPUT);
  digitalWrite(loadPin, HIGH);

  //Set up built-in LED as an OUTPUT and ensure that it is off as well:
  pinMode(ledPin, OUTPUT);
  digitalWrite(ledPin, LOW);

  Serial.println("OFF");

}  //END SETUP

void loop() {

  button1State = digitalRead(button1Pin);

  //if button is pressed, it will be pulled low
  if (button1State == LOW) {
    currentbutton1State = true;  // button has been pressed once

    if (prevbutton1State != currentbutton1State) {  //check to see if button is still being pressed

      if (mode == false) {
        mode = true;
      } else {
        mode = false;
      }

      if (mode == true) {

        digitalWrite(loadPin, LOW);
        digitalWrite(ledPin, HIGH);
        Serial.println("ON");

      } else {

        digitalWrite(loadPin, HIGH);
        digitalWrite(ledPin, LOW);
        Serial.println("OFF");
      }

      delay(500);  //add small delay, you may need to have a bigger delay for button debouncing

    } else {  //do nothing because finger is still on button
    }

    prevbutton1State = currentbutton1State;  //update button1 state
  }
  //button has not been pressed, it will be high
  else {

    currentbutton1State = false;
    prevbutton1State = currentbutton1State;  //update button1 state
  }

}  //END LOOP

```

#### What You Should See

Once the code has uploaded, disconnect the USB cable from the IoT RedBoard - ESP32. Then insert the barrel jack from a power supply to the MOSFET Power Switch and Buck Regulator's barrel jack connector. In this case, we used a 12V wall adapter power supply.

The load will be powered on as soon as the button is pressed. Releasing and pressing the button again will turn the load off. The built-in LED will light up every time the load is turned on. Of course, there is also a built-in LED on the MOSFET Power Switch and Buck Regulator that will light up whenever power is applied to the load as well. If necessary, disconnect the 3.3V jumper wire from the IoT RedBoard - ESP32, reconnect the USB cable, and open the [Arduino Serial Monitor](https://learn.sparkfun.com/tutorials/terminal-basics/arduino-serial-monitor-windows-mac-linux) at **115200** baud for debugging purposes.

<div style="text-align: center;">
  <table>
    <tr style="vertical-align:middle;">
     <td style="text-align: center; vertical-align: middle;"><a href="../assets/img/23979-MOSFET_Power_Switch_ESP32_Arduino_Solenoid_Latch_Lock_Momentary_Button.gif">DC Motor to MOSFET Power Switch</a></td>
    </tr>
  </table>
</div>

Even though this example used a button to toggle a latching solenoid, you can also use this example to control a DC motor or 12V LED! You can also try using the [Qwiic RFID with an RFID tag instead of a button to turn the solenoid on](https://www.sparkfun.com/news/2887). Just make sure to adjust the example code should you decide to use something else other than a button to contorl your load.

### Example 3: Fading

In this example, we will slowly turn on the load and then slowly turn it off using the N-channel MOSFET. This example is better with a DC motor and 12V LED. You will typically want the solenoid to be fully turned on/off.

#### Parts Needed

Grab the following quantities of each part listed to build this circuit:

* 1x [SparkFun IoT RedBoard - ESP32 Development Board](https://www.sparkfun.com/products/19177)
* 1x [USB-C Cable](https://www.sparkfun.com/products/15092)
* 3x [SparkFun MOSFET Power Switch and Buck Regulator (Low-Side)](https://www.sparkfun.com/products/23979)
* 1x [SparkFun Mini Screwdriver](https://www.sparkfun.com/products/9146)
* 3x [M/M Jumper Wires](https://www.sparkfun.com/products/8431)
* 1x [12V RGB LED Strip](https://www.sparkfun.com/products/12021)
* 1x [12V Wall Adapter Power Supply](https://www.sparkfun.com/products/15313)

#### Hardware Hookup

You will need to connect everything as explained earlier. For this particular example, we will use one channel from a 12V RGB LED strip as shown in the circuit diagram below.

<div style="text-align: center;">
  <table>
    <tr style="vertical-align:middle;">
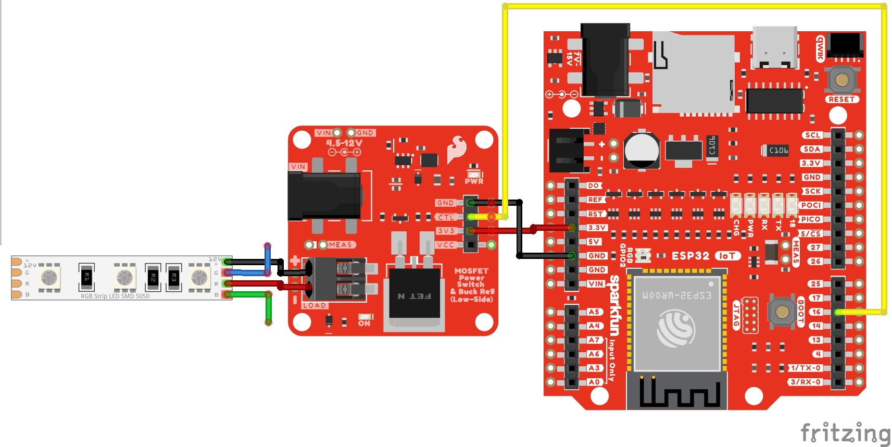
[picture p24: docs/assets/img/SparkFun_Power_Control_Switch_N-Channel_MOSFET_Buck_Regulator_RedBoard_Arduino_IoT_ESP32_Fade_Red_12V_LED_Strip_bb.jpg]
Red from a 12V RGB LED Strip, MOSFET Power Switch, IoT RedBoard - ESP32
     <td style="text-align: center; vertical-align: middle;"></td>
    </tr>
  </table>
</div>

!!! note
    Notice that we are using pin 16 to fade the red channel instead of pin 25 on the IoT RedBoard - ESP32.

Your setup should look similar to the image below without the power supply.

<div style="text-align: center;">
  <table>
    <tr style="vertical-align:middle;">
     <td style="text-align: center; vertical-align: middle;"><a href="../assets/img/23979-MOSFET_Power_Switch_ESP32_LED_Strip_Red_Fading.jpg">12V LED Strip to MOSFET Power Switch</a></td>
    </tr>
  </table>
</div>

#### Upload Code

To upload code, insert the USB cable into the IoT RedBoard - ESP32.

!!! note
    This example is similar to the built-in Arduino example. From the menu, select the following: **File** > **Examples** > **03.Analog** > **Fading**. You will need to modify the defined pin with a PWM pin for your microcontroller. Note that the logic is reversed due to the transistor.

Copy the following code and paste it in the Arduino IDE. If you have not already, select your Board (in this case, the **SparkFun ESP32 IoT RedBoard**), and associated COM port. Then hit the upload button.

``` c

/******************************************************************************
      Example 3: Fading
      Modified By: Ho Yun "Bobby" Chan
      SparkFun Electronics
      Date: October 27th, 2023
      License: MIT. See license file for more information but you can
      basically do whatever you want with this code.

      This example is based on Arduino's fade example. It has been modified
      so that it can be used for the SparkFun IoT RedBoard- ESP32 but it can be
      used with any Arduino that has a PWM pin. The load (DC motor,
      or 12V LED) will slowly turn on and off. This code will be more useful for
      users connecting a DC motor or nonaddressable LED so that you can partially
      turn on/off the load.

      Users can also open the Serial Monitor at 115200 to check on
      the status of the button for debugging.

      Feel like supporting open source hardware?
      Buy a board or component from SparkFun!

          SparkFun MOSFET Power Switch and Buck Regulator (Low-Side): https://www.sparkfun.com/products/23979
          SparkFun IoT RedBoard - ESP32 Development Board:            https://www.sparkfun.com/products/19177
          Hobby Motor - Gear:                                         https://www.sparkfun.com/products/11696
          Blower - Squirrel Cage (12V):                               https://www.sparkfun.com/products/11270
          12V LED RGB Strip - Bare (1m):                              https://www.sparkfun.com/products/12021
          Wall Adapter 12V/600mA, (Barrel Jack):                      https://www.sparkfun.com/products/15313

      Distributed as-is; no warranty is given.
    ******************************************************************************/

int loadPin = 16;

// the setup function runs once when you press reset or power the board
void setup() {

  //Initialize Serial for Debugging if there is no built-in LED
  Serial.begin(115200);
  Serial.println("Analog fade in and out to slowly turn on/off load!");

  // Set up the load pin to be an output and turn it off:
  pinMode(loadPin, OUTPUT);
  analogWrite(loadPin, 255);

  Serial.println("OFF");

}  //END SETUP

// the loop function runs over and over again forever
void loop() {

  Serial.println("<===== FADE IN =====>");
  // fade in from min to max in increments of 5 points:
  for (int fadeValue = 255; fadeValue >= 0; fadeValue -= 5) {
    // sets the value (range from 0 to 255):
    analogWrite(loadPin, fadeValue);
    // wait for 30 milliseconds to see the dimming effect
    delay(30);

    Serial.println(fadeValue);
  }

  Serial.println("<===== FADE OUT =====>");
  // fade out from max to min in increments of 5 points:
  for (int fadeValue = 0; fadeValue <= 255; fadeValue += 5) {
    // sets the value (range from 0 to 255):
    analogWrite(loadPin, fadeValue);
    // wait for 30 milliseconds to see the dimming effect
    delay(30);

    Serial.println(fadeValue);
  }

}  //END LOOP

```

#### What You Should See

Once the code has uploaded, disconnect the USB cable from the IoT RedBoard - ESP32. Then insert the barrel jack from a power supply to the MOSFET Power Switch and Buck Regulator's barrel jack connector. In this case, we used a 12V wall adapter power supply.

The load will slowly turn on and slowly turn off. This will loop forever until power is removed from the board. If necessary, disconnect the 3.3V jumper wire from the IoT RedBoard - ESP32, reconnect the USB cable, and open the [Arduino Serial Monitor](https://learn.sparkfun.com/tutorials/terminal-basics/arduino-serial-monitor-windows-mac-linux) at **115200** baud for debugging purposes.

<div style="text-align: center;">
  <table>
    <tr style="vertical-align:middle;">
     <td style="text-align: center; vertical-align: middle;"><a href="../assets/img/23979-MOSFET_Power_Switch_ESP32_LED_Strip_Red_Fading.gif">12V LED Strip to MOSFET Power Switch</a></td>
    </tr>
  </table>
</div>

While this example was used to turn on one channel of a 12V RGB LED strip, you could also use this example with a DC motor. Try using a potentiometer (or any 3.3V analog sensor) with the [`map()` function](https://www.arduino.cc/reference/en/language/functions/math/map/) to adjust the speed of the motor.

### Example 4: 12V RGB LED Strip

In this example, we will control all three channels of the RGB LED strip. Since we've already [hooked up a 12V RGB LED strip before](https://learn.sparkfun.com/tutorials/non-addressable-rgb-led-strip-hookup-guide), we will also a circuit with a potentiometer to cycle between each color and a photoresistor to turn on the LEDs whenever the light is below a certain light level. The following example code is based on the [SparkFun Inventor's Kit v4.1 Night Light example](https://learn.sparkfun.com/tutorials/sparkfun-inventors-kit-experiment-guide---v41/circuit-1d-rgb-night-light).

<div class="grid cards hide col-4" markdown>
<!-- ----------WHITE SPACE BETWEEN GRID CARDS---------- -->
-   <a href="https://learn.sparkfun.com/tutorials/non-addressable-rgb-led-strip-hookup-guide/">
      <figure markdown>
        Non-Addressable RGB LED Strip Hookup Guide
      </figure>
    </a>

    ---

    <a href="https://learn.sparkfun.com/tutorials/non-addressable-rgb-led-strip-hookup-guide/">
      <b>Non-Addressable RGB LED Strip Hookup Guide</b>
    </a>
<!-- ----------WHITE SPACE BETWEEN GRID CARDS---------- -->
-   <a href="https://learn.sparkfun.com/tutorials/sparkfun-inventors-kit-experiment-guide---v41/circuit-1d-rgb-night-light">
      <figure markdown>
        SparkFun Inventor's Kit Experiment Guide - v4.1 | Circuit 1D: RGB Night-Light
      </figure>
    </a>

    ---

    <a href="https://learn.sparkfun.com/tutorials/sparkfun-inventors-kit-experiment-guide---v41/circuit-1d-rgb-night-light">
      <b>SparkFun Inventor's Kit Experiment Guide - v4.1 | Circuit 1D: RGB Night-Light</b>
    </a>
<!-- ----------WHITE SPACE BETWEEN GRID CARDS---------- -->

</div>

#### Parts Needed

Grab the following quantities of each part listed to build this circuit:

* 1x [SparkFun IoT RedBoard - ESP32 Development Board](https://www.sparkfun.com/products/19177)
* 1x [USB-C Cable](https://www.sparkfun.com/products/15092)
* 3x [SparkFun MOSFET Power Switch and Buck Regulator (Low-Side)](https://www.sparkfun.com/products/23979)
* 1x [SparkFun Mini Screwdriver](https://www.sparkfun.com/products/9146)
* 19x [M/M Jumper Wires](https://www.sparkfun.com/products/11026)*
* 1x [Breadboard](https://www.sparkfun.com/products/12002)
* 1x [10k&ohm; Potentiometer with Knob](https://www.sparkfun.com/products/9806)
* 1x [Mini Photocell](https://www.sparkfun.com/products/9088)
* 1x [10k&ohm; Resistor](https://www.sparkfun.com/products/14491)
* 1x [12V RGB LED Strip](https://www.sparkfun.com/products/12021)
* 1x [DC Barrel Jack Adapter - Male](https://www.sparkfun.com/products/10287)
* 3x [DC Barrel Jack Adapter - Female](https://www.sparkfun.com/products/10288)
* 1x [12V Wall Adapter](https://www.sparkfun.com/products/15313)

!!! note "* Note"
    You will need a minimum of 19x M/M jumper wires. Six jumper wires were stripped wires that connect the barrel jacks together for power and reference ground.

#### Hardware Hookup

For this particular example, we will use three channels from a 12V RGB LED strip while also including a similar circuit from the SparkFun Inventor's Kit v4.1. The circuit diagram is shown below.

<div style="text-align: center;">
  <table>
    <tr style="vertical-align:middle;">
     <td style="text-align: center; vertical-align: middle;"><a href="../assets/img/SparkFun_Power_Control_Switch_N-Channel_MOSFET_Buck_Regulator_RedBoard_Arduino_IoT_ESP32_Nightlight_RGB_12V_LED_Strip_bb.jpg">RGB 12V LED NightLight Example</a></td>
    </tr>
  </table>
</div>

!!! note
    When testing the non-addressable LED strip, the pin labeled "G" was actually blue and the "B" was actually green. Depending on the manufacturer, the label may vary. Try testing the LED strip out with a power supply to determine if the letter represents the color.

Keep in mind that instead of the RedBoard with ATmega328P, we are using the IoT RedBoard with ESP32.
Since the hardware is different, the following code was modified:

    - analog and PWM pins were redefined in the example code
    - threshold was modified due to the ADC's higher resolution
    - logic is reversed due to the transistors

!!! danger
    The IoT RedBoard with ESP32 has a system voltage of 3.3V. Thus, the logic levels is 3.3V instead of 5V on the RedBoard with ATmega328P. Thus, the analog reference voltage for the potentiometer and photoresistor is 3.3V. Make sure you are using 3.3V!

Your setup should look similar to the image below without the power supply.

<div style="text-align: center;">
  <table>
    <tr style="vertical-align:middle;">
     <td style="text-align: center; vertical-align: middle;"><a href="../assets/img/23979-ESP32_Three_MOSFET_Power_Switch_LEDs_RGB_NightLight_Photoresistor.jpg">RGB 12V LED Night Light Example</a></td>
    </tr>
  </table>
</div>

#### Upload Code

To upload code, insert the USB cable into the IoT RedBoard - ESP32.

Copy the following code and paste it in the Arduino IDE. If you have not already, select your Board (in this case, the **SparkFun ESP32 IoT RedBoard**), and associated COM port. Then hit the upload button.

``` c
/*
  12V RGB LED Nightlight Example

  Turns an 12V RGB strip LED on or off based on the light level read by a photoresistor.
  Change colors by turning the potentiometer. This example is based off the SparkFun
  Inventor's Kit v4.2 RGB Night-Light Example:

      https://learn.sparkfun.com/tutorials/sparkfun-inventors-kit-experiment-guide---v41

  Note that instead of the RedBoard with ATmega328P, we are using the IoT RedBoard with ESP32.
  Since the hardware is different, the following code was modified:

      - analog and PWM pins were redifined
      - threshold was modified due to the ADC's higher resolution
      - logic is reversed due to the transistors

  WARNING: Since the IoT RedBoard with ESP32 has a system voltage of 3.3V, the logic levels
  is 3.3V instead of 5V on the RedBoard with ATmega328P. Thus, the analog reference voltage
  for the potentiometer and photoresistor is 3.3V. Make sure you are using 3.3V!

  This sketch was written by SparkFun Electronics, with lots of help from the Arduino community.
  This code is completely free for any use.

*/

int photoresistor = A4;          //variable for storing the photoresistor value
int potentiometer = A5;          //this variable will hold a value based on the position of the knob
int threshold = 3000;            //if the photoresistor reading is lower than this value the light will turn on
                                 /*Note: The ESP32's ADC resolution is bigger. The max is 4095. In a bright room
                                 with your finger covering the sensor, the threshold was about 3000. In a dimly
                                 lit room, the threshold was about 1000. You will need to adjust this value when
                                 installing it in a room. Just make sure to make it a little more than the thresholed
                                 of the room. Try adding a button and some code  to save the threshold value! */

//LEDs are connected to these pins
int RedPin = 16;
int GreenPin = 17;
int BluePin = 25;

void setup() {
  Serial.begin(115200);           //start a serial connection with the computer
  Serial.println("12V RGB LED Strip Nightlight!");

  //set the LED pins to output
  pinMode(RedPin, OUTPUT);
  pinMode(GreenPin, OUTPUT);
  pinMode(BluePin, OUTPUT);

} //END SETUP

void loop() {

  photoresistor = analogRead(A4);         //read the value of the photoresistor
  potentiometer = analogRead(A5);         //read the value of the potentiometer

  Serial.print("Photoresistor value:");
  Serial.print(photoresistor);          //print the photoresistor value to the serial monitor
  Serial.print("  Potentiometer value:");
  Serial.println(potentiometer);          //print the potentiometer value to the serial monitor

  if (photoresistor < threshold) {        //if it's dark (the photoresistor value is below the threshold) turn the LED on
    //These nested if statements check for a variety of ranges and
    //call different functions based on the current potentiometer value.
    //Those functions are found at the bottom of the sketch.

    /*Note: We divided 4095 by 7 colors and had a window of about 585. For users
            Adding more colors, try dividing 4095 by the total number and adjust
            eac condition statement*/

    if (potentiometer > 0 && potentiometer <= 585)
      red();
    if (potentiometer > 585 && potentiometer <= 1170)
      orange();
    if (potentiometer > 1170 && potentiometer <= 1755)
      yellow();
    if (potentiometer > 1755 && potentiometer <= 2340)
      green();
    if (potentiometer > 2340 && potentiometer <= 2925)
      cyan();
    if (potentiometer > 2925 && potentiometer <= 3510)
      blue();
    if (potentiometer > 3510)
      magenta();
  }
  else {                                //if it isn't dark turn the LED off

    turnOff();                            //call the turn off function

  }

  delay(100);                             //short delay so that the printout is easier to read

} //END LOOP

void red () {

  //set the LED pins to values that make red
  analogWrite(RedPin, 0);
  analogWrite(GreenPin, 255);
  analogWrite(BluePin, 255);
}
void orange () {

  //set the LED pins to values that make orange
  analogWrite(RedPin, 0);
  analogWrite(GreenPin, 128);
  analogWrite(BluePin, 255);
}
void yellow () {

  //set the LED pins to values that make yellow
  analogWrite(RedPin, 0);
  analogWrite(GreenPin, 0);
  analogWrite(BluePin, 255);
}
void green () {

  //set the LED pins to values that make green
  analogWrite(RedPin, 255);
  analogWrite(GreenPin, 0);
  analogWrite(BluePin, 255);
}
void cyan () {

  //set the LED pins to values that make cyan
  analogWrite(RedPin, 255);
  analogWrite(GreenPin, 0);
  analogWrite(BluePin, 0);
}
void blue () {

  //set the LED pins to values that make blue
  analogWrite(RedPin, 255);
  analogWrite(GreenPin, 255);
  analogWrite(BluePin, 0);
}
void magenta () {

  //set the LED pins to values that make magenta
  analogWrite(RedPin, 0);
  analogWrite(GreenPin, 255);
  analogWrite(BluePin, 0);
}
void turnOff () {

  //set all three LED pins to 0 or OFF
  analogWrite(RedPin, 255);
  analogWrite(GreenPin, 255);
  analogWrite(BluePin, 255);
}

```

#### What You Should See

Once the code has uploaded, disconnect the USB cable from the IoT RedBoard - ESP32. Then insert the barrel jack from a power supply to the MOSFET Power Switch and Buck Regulator's barrel jack connector. In this case, we used a 12V wall adapter power supply.

The MOSFET Power Switch & Buck Regulator with the wall adapter. Cover the photoresistor with your finger (or just turn off the lights in the room) and turn the potentiometer. You should notice the colors cycling through as the potentiometer is within certain ranges. You will probably want to disconnect the 3.3V jumper wire from the IoT RedBoard - ESP32, reconnect the USB cable, and open the [Arduino Serial Monitor](https://learn.sparkfun.com/tutorials/terminal-basics/arduino-serial-monitor-windows-mac-linux) at **115200** baud for debugging purposes. That way you can view the serial data and adjust the threshold value based on the lighting in the room.

<div style="text-align: center;">
  <table>
    <tr style="vertical-align:middle;">
     <td style="text-align: center; vertical-align: middle;"><a href="../assets/img/23979-ESP32_Three_MOSFET_Power_Switch_LEDs_RGB_NightLight_Photoresistor.gif">RGB LEDs cycling as we turn the knob</a></td>
    </tr>
  </table>
</div>

Now that we have ported the example from the RedBoard Qwiic with an ATmega328P to the RedBoard IoT Development Board - ESP32, try adjusting the condition statement with the potentiometer to add additional colors. Or even writing some code save the threshold value whenever a button is pressed down. You can also try to take advantage of the ESP32's wireless capabilities and adjust the color of the LED strip based on the weather.

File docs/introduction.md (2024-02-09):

Does your microcontroller need to control a high voltage item, like a 12V LED strip, while needing to be powered as well? Do you want to avoid having multiple power adapters for your project and microcontroller? The [MOSFET Power Switch and Buck Regulator (Low-Side)](https://www.sparkfun.com/products/23979) is one of those products that we needed ourselves at SparkFun, so we figured other folks may have the same problem. Power the board with up to 12V and control up to 10A, all while providing a sweet 3.3V to your control board.

<center>
<div class="grid cards" style="width:500px;" markdown>

-   <a href="https://www.sparkfun.com/products/23979">
      <figure markdown>
        SparkFun MOSFET Power Switch and Buck Regulator (Low-Side)
      </figure>
    </a>

    ---

    <a href="https://www.sparkfun.com/products/23979">
      <b>SparkFun MOSFET Power Switch and Buck Regulator (Low-Side)</b>
      <br />
      COM-23979
      <br />
      <center>[Purchase from SparkFun :fontawesome-solid-cart-plus:](https://www.sparkfun.com/products/23979){ .md-button .md-button--primary }</center>
    </a>

</div>
</center>

In this tutorial, we will go over the hardware, how to connect to the board, and provide some Arduino examples.

### Required Materials

To follow along with this tutorial, you will need the following materials. We made a general list below since there are several options available to connect to the MOSFET Power Control and Buck Regulator (Low-Side). We'll list the specific parts used in each of the examples later in the tutorial. You may not need everything though depending on what you have. Add it to your cart, read through the guide, and adjust the cart as necessary.

* 1x Microcontroller
* 1x USB Cable
* 1x SparkFun MOSFET Power Switch and Buck Regulator (Low-Side)
* 1x SparkFun Mini Screwdriver
* 1x Pack of Jumper Wires
* 1x High Power Load
* 1x Wall Adapter

#### Microcontroller

For the scope of the tutorial, we will be using an Arduino microcontroller. In this case, we will be using the SparkFun IoT RedBoard - ESP32. You can use any Arduino microcontroller with digital or PWM pins. Make sure to also include a USB cable that is compatible with your microcontroller.

<div class="grid cards hide col-4" markdown>

<!-- ----------WHITE SPACE BETWEEN PRODUCTS---------- -->
-   <a href="https://www.sparkfun.com/products/19177">
      <figure markdown>
        SparkFun IoT RedBoard - ESP32 Development Board
      </figure>
    </a>

    ---

    <a href="https://www.sparkfun.com/products/19177">
      <b>SparkFun IoT RedBoard - ESP32 Development Board</b>
      <br />
      WRL-19177
    </a>
<!-- ----------WHITE SPACE BETWEEN PRODUCTS---------- -->
-   <a href="https://www.sparkfun.com/products/15092">
      <figure markdown>
        Reversible USB A to C Cable - 0.8m
      </figure>
    </a>

    ---

    <a href="https://www.sparkfun.com/products/15092">
      <b>Reversible USB A to C Cable - 0.8m</b>
      <br />
      CAB-15092
    </a>
<!-- ----------WHITE SPACE BETWEEN PRODUCTS---------- -->

</div>

!!! tip
    The 3.3V output from the MOSFET Power Switch and Buck Regulator (Low-Side) provides another alternative to power microcontrollers that may not be able to accept higher voltages. For example, most of the [Thing Plus Development Boards](https://www.sparkfun.com/thing_plus) only accept a maximum of 6V at their VIN pin, and they most operate at 3.3V. So this board is especially handy in those use-cases. Additionally, even though the Arduino Pro Mini can accept up to 12V, this will require its onboard linear regulator to work very had to regulate that voltage down to 3.3V. Thus, this MOSFET Power Switch and Buck Regulator (Low-Side) would be the "cooler" choice.

!!! note
    The tutorial focuses on using a microcontroller with Arduino. However, if your microcontroller has a digital or PWM, you can also control the N-channel MOSFET controller as well! You can also use this using a micro:bit with MakeCode or Raspberry Pi's RP2040 microcontroller with MicroPython!

#### 12V LEDs

The MOSFET Power Switch and Buck Regulator (Low-Side) can control 12V LEDs. For users with a 12V RGB LED strip, you can control one channel.

<div class="grid cards hide col-4" markdown>

<!-- ----------WHITE SPACE BETWEEN PRODUCTS---------- -->
-   <a href="https://www.sparkfun.com/products/12021">
      <figure markdown>
        LED RGB Strip - Bare (1m)
      </figure>
    </a>

    ---

    <a href="https://www.sparkfun.com/products/12021">
      <b>LED RGB Strip - Bare (1m)</b>
      <br />
      COM-12021
    </a>
<!-- ----------WHITE SPACE BETWEEN PRODUCTS---------- -->

</div>

#### Motors

There are a variety of motors with different ratings. Below are a few different motors that you could use for users that just need a motor to spin in one direction.

<div class="grid cards hide col-4" markdown>

<!-- ----------WHITE SPACE BETWEEN PRODUCTS---------- -->
-   <a href="https://www.sparkfun.com/products/11270">
      <figure markdown>
        Blower - Squirrel Cage (12V)
      </figure>
    </a>

    ---

    <a href="https://www.sparkfun.com/products/11270">
      <b>Blower - Squirrel Cage (12V)</b>
      <br />
      COM-11270
    </a>
<!-- ----------WHITE SPACE BETWEEN PRODUCTS---------- -->

-   <a href="https://www.sparkfun.com/products/11696">
      <figure markdown>
        Hobby Motor - Gear
      </figure>
    </a>

    ---

    <a href="https://www.sparkfun.com/products/11696">
      <b>Hobby Motor - Gear</b>
      <br />
      ROB-11696
    </a>
<!-- ----------WHITE SPACE BETWEEN PRODUCTS---------- -->
-   <a href="https://www.sparkfun.com/products/15277">
      <figure markdown>
        Planetary Gearmotor - 140RPM
      </figure>
    </a>

    ---

    <a href="https://www.sparkfun.com/products/15277">
      <b>Planetary Gearmotor - 140RPM</b>
      <br />
      ROB-15277
    </a>
<!-- ----------WHITE SPACE BETWEEN PRODUCTS---------- -->
-   <a href="https://www.sparkfun.com/products/10398">
      <figure markdown>
        Vacuum Pump - 12V
      </figure>
    </a>

    ---

    <a href="https://www.sparkfun.com/products/10398">
      <b>Vacuum Pump - 12V</b>
      <br />
      ROB-10398
    </a>
<!-- ----------WHITE SPACE BETWEEN PRODUCTS---------- -->
-   <a href="https://www.sparkfun.com/products/19222">
      <figure markdown>
        Liquid Pump - 500GPH (12V)
      </figure>
    </a>

    ---

    <a href="https://www.sparkfun.com/products/19222">
      <b>Liquid Pump - 500GPH (12V)</b>
      <br />
      ROB-19222
    </a>
<!-- ----------WHITE SPACE BETWEEN PRODUCTS---------- -->

</div>

#### Solenoid

Check below if you need a latching solenoid to lock a box of your secret stash of cookies, solenoid valve to water some plants, or even have the small solenoid tap a glass cup of water! Similar to the motors, each solenoid will have a different rating.

<div class="grid cards hide col-4" markdown>

<!-- ----------WHITE SPACE BETWEEN PRODUCTS---------- -->
-   <a href="https://www.sparkfun.com/products/15324">
      <figure markdown>
        Solenoid - 12V (Latch / Lock)
      </figure>
    </a>

    ---

    <a href="https://www.sparkfun.com/products/15324">
      <b>Solenoid - 12V (Latch / Lock)</b>
      <br />
      ROB-15324
    </a>
<!-- ----------WHITE SPACE BETWEEN PRODUCTS---------- -->

-   <a href="https://www.sparkfun.com/products/10456">
      <figure markdown>
        12V Solenoid Valve - 3/4 Inch
      </figure>
    </a>

    ---

    <a href="https://www.sparkfun.com/products/10456">
      <b>12V Solenoid Valve - 3/4"</b>
      <br />
      ROB-10456
    </a>
<!-- ----------WHITE SPACE BETWEEN PRODUCTS---------- -->
-   <a href="https://www.sparkfun.com/products/11015">
      <figure markdown>
        Solenoid - 5V (Small)
      </figure>
    </a>

    ---

    <a href="https://www.sparkfun.com/products/11015">
      <b>Solenoid - 5V (Small)</b>
      <br />
      ROB-11015
    </a>
<!-- ----------WHITE SPACE BETWEEN PRODUCTS---------- -->

</div>

#### Heating Element

Feeling cold? Try adding a small heating pad to warm up your hands or even a horse bit for an early morning ride! Or maybe you want to make a mini-refrigerator to keep your drinks cool with a thermoelectric cooler.

<div class="grid cards hide col-4" markdown>

<!-- ----------WHITE SPACE BETWEEN PRODUCTS---------- -->
-   <a href="https://www.sparkfun.com/products/11288">
      <figure markdown>
        Heating Pad - 5x10cm
      </figure>
    </a>

    ---

    <a href="https://www.sparkfun.com/products/11288">
      <b>Heating Pad - 5x10cm</b>
      <br />
      COM-11288
    </a>
<!-- ----------WHITE SPACE BETWEEN PRODUCTS---------- -->

-   <a href="https://www.sparkfun.com/products/11289">
      <figure markdown>
        Heating Pad - 5x15cm
      </figure>
    </a>

    ---

    <a href="https://www.sparkfun.com/products/11289">
      <b>Heating Pad - 5x15cm</b>
      <br />
      COM-11289
    </a>
<!-- ----------WHITE SPACE BETWEEN PRODUCTS---------- -->
-   <a href="https://www.sparkfun.com/products/15082">
      <figure markdown>
        Thermoelectric Cooler
      </figure>
    </a>

    ---

    <a href="https://www.sparkfun.com/products/15082">
      <b>Thermoelectric Cooler</b>
      <br />
      COM-15082
    </a>
<!-- ----------WHITE SPACE BETWEEN PRODUCTS---------- -->

</div>

#### Heatsink

Is your MOSFET getting too hot to the touch? You can add a small heatsink to [help dissipate some heat](https://learn.sparkfun.com/tutorials/understanding-thermal-resistance). The small heatsink listed below fits the exposed ground plane on the back of the board. If you need a slightly bigger heat sink, there is also the copper heatsink (note that it's a little bigger than the size of the exposed ground plane). You can also use the copper heatsink with the thermoelectric cooler listed above.

<div class="grid cards hide col-4" markdown>

<!-- ----------WHITE SPACE BETWEEN PRODUCTS---------- -->
-   <a href="https://www.sparkfun.com/products/11510">
      <figure markdown>
        Heating Pad - 5x10cm
      </figure>
    </a>

    ---

    <a href="https://www.sparkfun.com/products/11510">
      <b>Small Heatsink</b>
      <br />
      PRT-11510
    </a>
<!-- ----------WHITE SPACE BETWEEN PRODUCTS---------- -->
-   <a href="https://www.sparkfun.com/products/17054">
      <figure markdown>
        Heating Pad - 5x15cm
      </figure>
    </a>

    ---

    <a href="https://www.sparkfun.com/products/17054">
      <b>Thermal Tape 4x4" Square</b>
      <br />
      PRT-17054
    </a>
<!-- ----------WHITE SPACE BETWEEN PRODUCTS---------- -->

-   <a href="https://www.sparkfun.com/products/18704">
      <figure markdown>
        Heatsink - 13.20 x 12.10 mm (Copper)
      </figure>
    </a>

    ---

    <a href="https://www.sparkfun.com/products/18704">
      <b>Heatsink - 13.20 x 12.10 mm (Copper)</b>
      <br />
      PRT-18704
    </a>
<!-- ----------WHITE SPACE BETWEEN PRODUCTS---------- -->

</div>

#### Power Supply

The power supply that you use will depend on your load and project requirements. For example, the [small solenoid](https://www.sparkfun.com/products/11015) is rated for 5V while the [latching solenoid](https://www.sparkfun.com/products/15324) is rated for 12V. Below are a [few power supplies available in SparkFun's catalog](https://www.sparkfun.com/categories/308). Not sure which power supply that you need? Try grabbing the power supply sample kit!

<div class="grid cards hide col-4" markdown>

<!-- ----------WHITE SPACE BETWEEN PRODUCTS---------- -->
-   <a href="https://www.sparkfun.com/products/19194">
      <figure markdown>
        SparkFun Power Supply Sample Kit
      </figure>
    </a>

    ---

    <a href="https://www.sparkfun.com/products/19194">
      <b>SparkFun Power Supply Sample Kit</b>
      <br />
      KIT-19194
    </a>
<!-- ----------WHITE SPACE BETWEEN PRODUCTS---------- -->
-   <a href="https://www.sparkfun.com/products/15313">
      <figure markdown>
        Wall Adapter Power Supply - 12VDC, 600mA (Barrel Jack)
      </figure>
    </a>

    ---

    <a href="https://www.sparkfun.com/products/15313">
      <b>Wall Adapter Power Supply - 12VDC, 600mA (Barrel Jack)</b>
      <br />
      TOL-15313
    </a>
<!-- ----------WHITE SPACE BETWEEN PRODUCTS---------- -->
-   <a href="https://www.sparkfun.com/products/15314">
      <figure markdown>
        Wall Adapter Power Supply - 9VDC, 650mA (Barrel Jack)
      </figure>
    </a>

    ---

    <a href="https://www.sparkfun.com/products/15313">
      <b>Wall Adapter Power Supply - 9VDC, 650mA (Barrel Jack)</b>
      <br />
      TOL-15314
    </a>
<!-- ----------WHITE SPACE BETWEEN PRODUCTS---------- -->
-   <a href="https://www.sparkfun.com/products/15312">
      <figure markdown>
        Wall Adapter Power Supply - 5VDC, 2A (Barrel Jack)
      </figure>
    </a>

    ---

    <a href="https://www.sparkfun.com/products/15312">
      <b>Wall Adapter Power Supply - 5VDC, 2A (Barrel Jack)</b>
      <br />
      TOL-15313
    </a>
<!-- ----------WHITE SPACE BETWEEN PRODUCTS---------- -->

</div>

If you decided to connect a few MOSFET Power Switch and Buck Regulators (Low-Side) together using the same power supply, you may want to include the following barrel jack adapters.

<div class="grid cards hide col-4" markdown>

<!-- ----------WHITE SPACE BETWEEN PRODUCTS---------- -->
-   <a href="https://www.sparkfun.com/products/10287">
      <figure markdown>
        DC Barrel Jack Adapter - Male
      </figure>
    </a>

    ---

    <a href="https://www.sparkfun.com/products/10287">
      <b>DC Barrel Jack Adapter - Male</b>
      <br />
      PRT-10287
    </a>
<!-- ----------WHITE SPACE BETWEEN PRODUCTS---------- -->
-   <a href="https://www.sparkfun.com/products/10288">
      <figure markdown>
        DC Barrel Jack Adapter - Female
      </figure>
    </a>

    ---

    <a href="https://www.sparkfun.com/products/10288">
      <b>DC Barrel Jack Adapter - Female</b>
      <br />
      PRT-10288
    </a>
<!-- ----------WHITE SPACE BETWEEN PRODUCTS---------- -->

</div>

#### Prototyping Accessories _(Optional)_

We've designed the board to allow for an easy connection with the rest of the system using M/M jumper wires. Depending on your application, you can solder header pins or you may need an additional breadboard. Below are a few prototyping accessories that you may want to consider.

<div class="grid cards col-4" markdown>
<!-- ----------WHITE SPACE BETWEEN PRODUCTS---------- -->
-   <a href="https://www.sparkfun.com/products/12045">
      <figure markdown>
        Breadboard - Mini Modular (Blue)
      </figure>
    </a>

    ---

    <a href="https://www.sparkfun.com/products/12045">
      <b>Breadboard - Mini Modular (Blue)</b>
      <br />
      PRT-12045
    </a>
<!-- ----------WHITE SPACE BETWEEN PRODUCTS---------- -->
-   <a href="https://www.sparkfun.com/products/12002">
      <figure markdown>
        Breadboard - Self-Adhesive (White)
      </figure>
    </a>

    ---

    <a href="https://www.sparkfun.com/products/12002">
      <b>Breadboard - Self-Adhesive (White)</b>
      <br />
      PRT-12002
    </a>
<!-- ----------WHITE SPACE BETWEEN PRODUCTS---------- -->
-   <a href="https://www.sparkfun.com/products/115">
      <figure markdown>
        Female Headers
      </figure>
    </a>

    ---

    <a href="https://www.sparkfun.com/products/115">
      <b>Female Headers</b>
      <br />
      PRT-00115
    </a>
<!-- ----------WHITE SPACE BETWEEN PRODUCTS---------- -->
-   <a href="https://www.sparkfun.com/products/116">
      <figure markdown>
        Break Away Headers - Straight
      </figure>
    </a>

    ---

    <a href="https://www.sparkfun.com/products/116">
      <b>Break Away Headers - Straight</b>
      <br />
      PRT-00116
    </a>
<!-- ----------WHITE SPACE BETWEEN PRODUCTS---------- -->
-   <a href="https://www.sparkfun.com/products/9140">
      <figure markdown>
        Jumper Wires Premium 6
      <br>
      PRT-09140
    </a>
<!-- ----------WHITE SPACE BETWEEN PRODUCTS---------- -->
-   <a href="https://www.sparkfun.com/products/8431">
      <figure markdown>
        Jumper Wires Premium 6
      <br />
      PRT-08431
    </a>
<!-- ----------WHITE SPACE BETWEEN PRODUCTS---------- -->
-   <a href="https://www.sparkfun.com/products/11026">
      <figure markdown>
        Jumper Wires Standard 7
      <br />
      PRT-11026
    </a>
<!-- ----------WHITE SPACE BETWEEN PRODUCTS---------- -->
</div>

#### Tools _(Optional)_

Besides the mini screwdriver, there may be other tools that you may need. For a secure connection, you will need to solder two wires between your microcontroller and the breakout board. This requires some assembly and soldering. You may already have a few of these items but if not, the tools and hardware below help with that assembly.

<div class="grid cards hide col-4" markdown>

<!-- ----------WHITE SPACE BETWEEN PRODUCTS---------- -->
-   <a href="https://www.sparkfun.com/products/9146">
      <figure markdown>
        SparkFun Mini Screwdriver
      </figure>
    </a>

    ---

    <a href="https://www.sparkfun.com/products/9146">
      <b>SparkFun Mini Screwdriver</b>
      <br />
      TOL-09146
    </a>
<!-- ----------WHITE SPACE BETWEEN PRODUCTS---------- -->
-   <a href="https://www.sparkfun.com/products/11375">
      <figure markdown>
        Hook-Up Wire - Assortment (Stranded, 22 AWG)
      </figure>
    </a>

    ---

    <a href="https://www.sparkfun.com/products/11375">
      <b>Hook-Up Wire - Assortment (Stranded, 22 AWG)</b>
      <br />
      PRT-11375
    </a>
<!-- ----------WHITE SPACE BETWEEN PRODUCTS---------- -->
-   <a href="https://www.sparkfun.com/products/22263">
      <figure markdown>
        Wire Stripper - 20-30 AWG Solid (22-32 AWG Stranded)
      </figure>
    </a>

    ---

    <a href="https://www.sparkfun.com/products/22263">
      <b>Wire Stripper - 20-30 AWG Solid (22-32 AWG Stranded)</b>
      <br />
      TOL-22263
    </a>
<!-- ----------WHITE SPACE BETWEEN PRODUCTS---------- -->
-   <a href="https://www.sparkfun.com/products/24063">
      <figure markdown>
        PINECIL Soldering Iron Kit
      </figure>
    </a>

    ---

    <a href="https://www.sparkfun.com/products/24063">
      <b>PINECIL Soldering Iron Kit</b>
      <br />
      TOL-24063
    </a>
<!-- ----------WHITE SPACE BETWEEN PRODUCTS---------- -->
-   <a href="https://www.sparkfun.com/products/9163">
      <figure markdown>
        Solder Lead Free - 15-gram Tube
      </figure>
    </a>

    ---

    <a href="https://www.sparkfun.com/products/9163">
      <b>Solder Lead Free - 15-gram Tube</b>
      <br>
      TOL-09163
    </a>
<!-- ----------WHITE SPACE BETWEEN PRODUCTS---------- -->
</div>

#### You Will Also Need

If you decide to do some "magic," try grabbing the following with the squirrel cage blower.

* Ping Pong Ball

### Suggested Reading

If you aren’t familiar with the following concepts, we also recommend checking out a few of these tutorials before continuing.

<div class="grid cards hide col-4" markdown>
<!-- ----------WHITE SPACE BETWEEN GRID CARDS---------- -->
-   <a href="https://learn.sparkfun.com/tutorials/transistors">
      <figure markdown>
        Transistors
      </figure>
    </a>

    ---

    <a href="https://learn.sparkfun.com/tutorials/transistors">
      <b>Transistors</b>
    </a>
<!-- ----------WHITE SPACE BETWEEN GRID CARDS---------- -->
-   <a href="https://learn.sparkfun.com/tutorials/diodes">
      <figure markdown>
        Diodes
      </figure>
    </a>

    ---

    <a href="https://learn.sparkfun.com/tutorials/diodes">
      <b>Diodes</b>
    </a>
<!-- ----------WHITE SPACE BETWEEN GRID CARDS---------- -->
-   <a href="https://learn.sparkfun.com/tutorials/logic-levels/all">
      <figure markdown>
        Logic Levels
      </figure>
    </a>

    ---

    <a href="https://learn.sparkfun.com/tutorials/logic-levels/all">
      <b>Logic Levels</b>
    </a>
<!-- ----------WHITE SPACE BETWEEN GRID CARDS---------- -->

-   <a href="https://learn.sparkfun.com/tutorials/iot-redboard-esp32-development-board-hookup-guide">
      <figure markdown>
        IoT RedBoard ESP32 Development Board Hookup Guide
      </figure>
    </a>

    ---

    <a href="https://learn.sparkfun.com/tutorials/iot-redboard-esp32-development-board-hookup-guide">
      <b>IoT RedBoard ESP32 Development Board Hookup Guide</b>
    </a>
<!-- ----------WHITE SPACE BETWEEN GRID CARDS---------- -->
-   <a href="https://learn.sparkfun.com/tutorials/motors-and-selecting-the-right-one/all">
      <figure markdown>
        Motors and Selecting the Right One
      </figure>
    </a>

    ---

    <a href="https://learn.sparkfun.com/tutorials/motors-and-selecting-the-right-one/all">
      <b>Motors and Selecting the Right One</b>
    </a>
<!-- ----------WHITE SPACE BETWEEN GRID CARDS---------- -->
-   <a href="https://learn.sparkfun.com/tutorials/non-addressable-rgb-led-strip-hookup-guide">
      <figure markdown>
        Non-Addressable RGB LED Strip Hookup Guide
      </figure>
    </a>

    ---

    <a href="https://learn.sparkfun.com/tutorials/non-addressable-rgb-led-strip-hookup-guide">
      <b>Non-Addressable RGB LED Strip Hookup Guide</b>
    </a>
<!-- ----------WHITE SPACE BETWEEN GRID CARDS---------- -->
-   <a href="https://learn.sparkfun.com/tutorials/terminal-basics">
      <figure markdown>
        Serial Terminal Basics
      </figure>
    </a>

    ---

    <a href="https://learn.sparkfun.com/tutorials/terminal-basics">
      <b>Serial Terminal Basics</b>
    </a>
<!-- ----------WHITE SPACE BETWEEN GRID CARDS---------- -->
-   <a href="https://learn.sparkfun.com/tutorials/how-to-solder-through-hole-soldering/all">
      <figure markdown>
        How to Solder: Through Hole Soldering
      </figure>
    </a>

    ---

    <a href="https://learn.sparkfun.com/tutorials/how-to-solder-through-hole-soldering/all">
      <b>How to Solder: Through Hole Soldering</b>
    </a>
<!-- ----------WHITE SPACE BETWEEN GRID CARDS---------- -->
-   <a href="https://learn.sparkfun.com/tutorials/working-with-wire/how-to-strip-a-wirel">
      <figure markdown>
        Working with Wire
      </figure>
    </a>

    ---

    <a href="https://learn.sparkfun.com/tutorials/working-with-wire/how-to-strip-a-wire">
      <b>Working with Wire</b>
    </a>
<!-- ----------WHITE SPACE BETWEEN GRID CARDS---------- -->
-   <a href="https://learn.sparkfun.com/tutorials/how-to-work-with-jumper-pads-and-pcb-traces/all">
      <figure markdown>
        How to Work with Jumper Pads and PCB Traces
      </figure>
    </a>

    ---

    <a href="https://learn.sparkfun.com/tutorials/how-to-work-with-jumper-pads-and-pcb-traces/all">
      <b>How to Work with Jumper Pads and PCB Traces</b>
    </a>
<!-- ----------WHITE SPACE BETWEEN GRID CARDS---------- -->
-   <a href="https://learn.sparkfun.com/tutorials/how-to-power-a-project/all">
      <figure markdown>
        How to Power a Project
      </figure>
    </a>

    ---

    <a href="https://learn.sparkfun.com/tutorials/how-to-power-a-project/all">
      <b>How to Power a Project</b>
    </a>
<!-- ----------WHITE SPACE BETWEEN GRID CARDS---------- -->
</div>

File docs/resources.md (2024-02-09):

Now that you've successfully got your SparkFun MOSFET Power Switch and Buck Regulator (Low-Side) up and running, it's time to incorporate it into your own project! For more information, check out the resources below:

* [Schematic (PDF)](../assets/board_files/SparkFun_MOSFET_Power_Switch_and_Buck_Regulator_Low-Side_Schematic_V11.pdf)
* [Eagle Files (ZIP)](../assets/board_files/SparkFun_MOSFET_Power_Switch_and_Buck_Regulator_Low-Side_V11.zip)
* [Board Dimensions (PNG)](../assets/img/SparkFun_MOSFET_Power_Switch_and_Buck_Regulator_Low-Side_Board_Dimensions.png)
* Datasheet
    * [LMR14203 (PDF)](../assets/component_documentation/lmr14203.pdf)
    * [PSMN7R0-100BS (PDF)](../assets/component_documentation/PSMN7R0-100BS.pdf)
* [GitHub Hardware Repo](https://github.com/sparkfun/SparkFun_MOSFET_Power_Switch_and_Buck_Regulator_Low-Side)

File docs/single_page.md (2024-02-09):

---
hide:
  - navigation
  - toc
icon: fontawesome/solid/scroll
---

# Introduction
--8<-- "./docs/introduction.md"

# Hardware Overview
--8<-- "./docs/hardware_overview.md"

# Hardware Hookup
--8<-- "./docs/hardware_hookup.md"

# Arduino Examples
--8<-- "./docs/arduino_examples.md"

# Troubleshooting
--8<-- "./docs/troubleshooting.md"

# Resources
--8<-- "./docs/resources.md"

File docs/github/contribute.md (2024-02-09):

# Contribute: Help Fix our Mistake!
Spot something wrong? Feel free to contribute our open-source design and documentation. 

## Improve our Documentation
All of this documentation can be modified by you! Please help us make it better.

* These pages are contained in the [`docs` folder of the SparkFun MOSFET Power Switch and Buck Regulator (Low-Side) repository](https://github.com/sparkfun/SparkFun_MOSFET_Power_Switch_and_Buck_Regulator_Low-Side/tree/main/docs).

### Submit a Correction
1. Fork this repo
2. Add your corrections or improvements to the markdown file
3. File a pull request with your changes, and enjoy making the ~~words~~ ~~worlds~~ world a better place.
    * Once received, the documentation specialist will automatically be notified.
    * We will review your suggested improvements to make sure they are correct and fit within our documentation standards.

## Improve our Hardware Design
All of our designs are open-source! Please help us make it better.

* Our board design files are contained in the [`Hardware` folder of the SparkFun MOSFET Power Switch and Buck Regulator (Low-Side) repository](https://github.com/sparkfun/SparkFun_MOSFET_Power_Switch_and_Buck_Regulator_Low-Side/tree/main/Hardware).

### Submit a Design Improvement
1. Fork this repo
2. Add your design improvements
3. File a pull request with your changes, and enjoy making the ~~words~~ ~~worlds~~ world a better place.
    * Once received, the engineer in charge of the original design will automatically be notified.
    * We will review your suggested improvements, if they are within our board design standards and meet our product design requirements, we will flag these changes for our next board revision. *(Please note, that even if your suggestion is accepted, these changes may not be immediate. We may have to cycle through our current product inventory first.)*

## Contributors
Let's provided some recognition to the contributors for this project!

GitHub Contributors Image
<br>


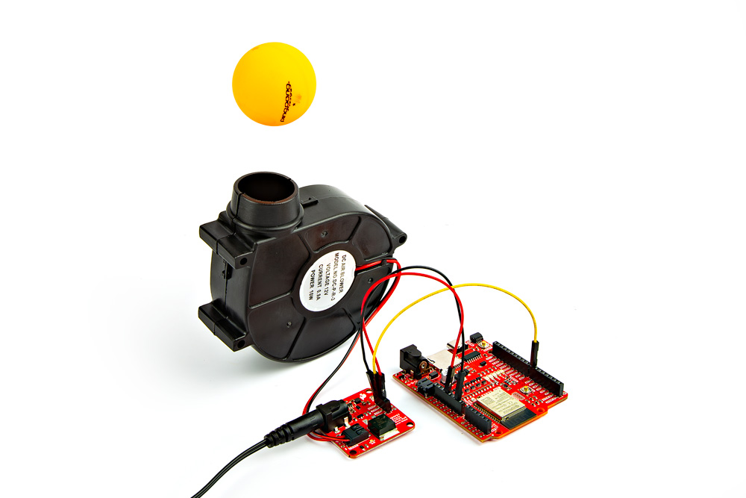
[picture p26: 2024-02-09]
docs/assets/img/23979-MOSFET_Power_Switch_ESP32_Arduino_Squirrel_Cage_Blower_Motor_levitating_Ping_Pong_Ball.jpg

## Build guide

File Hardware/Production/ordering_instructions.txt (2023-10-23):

panel size, 168x130mm
PCB thickness, 1.6mm
number of layers, 2
material, TG135
soldermask color, Red
silkscreen color, White
oz copper, 2oz
finish, HASL lead free
stencils, top
pcs per panel, 12
min trace width, 0.1778mm / 0.0070in
min drill size, 0.3048mm / 0.0120in

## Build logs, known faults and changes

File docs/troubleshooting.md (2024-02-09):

### General Troubleshooting Help

!!! note
    <span class="glyphicon glyphicon-question-sign" aria-hidden="true"></span>
        <strong> Not working as expected and need help? </strong> <br /><br />

    If you need technical assistance and more information on a product that is not working as you expected, we recommend heading on over to the <a href="https://www.sparkfun.com/technical_assistance">SparkFun Technical Assistance</a> page for some initial troubleshooting. <br /><br />

    <div style="text-align: center"><a href="https://www.sparkfun.com/technical_assistance" target="sfe_technical_assistance" class="md-button">SparkFun Technical Assistance Page</a></div>

    If you don't find what you need there, the <a href="https://forum.sparkfun.com/">SparkFun Forums</a> are a great place to find and ask for help. If this is your first visit, you'll need to <a href="https://forum.sparkfun.com/ucp.php?mode=register">create a Forum Account</a> to search product forums and post questions.<br /><br />

    <div style="text-align: center"><a href="https://forum.sparkfun.com/ucp.php?mode=register" class="md-button">Create New Forum Account</a>&nbsp;&nbsp;&nbsp;<a href="https://forum.sparkfun.com/viewforum.php?f=180" class="md-button md-button--primary">Log Into SparkFun Forums</a></div>

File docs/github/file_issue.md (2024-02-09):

# Did we make a mistake?

Spot something wrong? Please let us know. 

!!! attention
    This is not where customers should seek assistance on a product. If you require technical assistance or have questions about a product that is not working as expected, please head over to the [SparkFun Technical Assistance](https://www.sparkfun.com/technical_assistance) page for some initial troubleshooting.
    <center>
    [SparkFun Technical Assistance Page](https://www.sparkfun.com/technical_assistance){ .md-button .md-button--primary }
    </center>

    If you can't find what you need there, you'll need a [Forum Account](https://forum.sparkfun.com/ucp.php?mode=register) to search product forums and post questions.

## Discrepancies in the Documentation

All of this documentation can be modified by you! Please help us make it better.

* The documentation files for these pages are contained in the [`docs` folder of the SparkFun MOSFET Power Switch and Buck Regulator (Low-Side) repository](https://github.com/sparkfun/SparkFun_MOSFET_Power_Switch_and_Buck_Regulator_Low-Side/tree/main/docs).

### Spot something wrong?
If a section of the documentation is incorrect, please [open an issue](https://github.com/sparkfun/SparkFun_MOSFET_Power_Switch_and_Buck_Regulator_Low-Side/issues) and let us know.

### Do you have a suggested correction?
1. With a GitHub account, fork this repo
2. Add your correction(s) or improvement(s) to the markdown file(s)
3. File a pull request with your changes, and enjoy making the ~~words~~ ~~worlds~~ world a better place.
    * Once received, the documentation specialist will automatically be notified.
    * We will review your suggested improvement(s) to make sure they are correct and fit within our documentation standards.

## Problems in the Hardware Design

All of our designs are open-source! Please help us make it better.

* Our board design files are contained in the [`Hardware` folder of the SparkFun MOSFET Power Switch and Buck Regulator (Low-Side) repository](https://github.com/sparkfun/SparkFun_MOSFET_Power_Switch_and_Buck_Regulator_Low-Side/tree/main/Hardware).

### Does something not make sense?
If part of the design is confusing, please [open an issue](https://github.com/sparkfun/SparkFun_MOSFET_Power_Switch_and_Buck_Regulator_Low-Side/issues) and let us know.

### Did we forget to include an important function of the board?
* Please keep in mind that we may intentionally exclude certain functions of the board to meet our product design requirements. *(For example, our Qwiic Micro boards are intended to fit on a small board layout and only use I<sup>2</sup>C communication; therefore, we may not have the SPI and interrupt pins available for users.)*
* If part of the board's functionality is missing, please [open an issue](https://github.com/sparkfun/SparkFun_MOSFET_Power_Switch_and_Buck_Regulator_Low-Side/issues) and file a feature request.

### Do you wish to contribute directly to improving the board design?
1. With a GitHub account, Fork this repo
2. Add your design improvement(s)
3. File a pull request with your changes, and enjoy making the ~~words~~ ~~worlds~~ world a better place.
    * Once received, the engineer in charge of the original design will automatically be notified.
    * We will review your suggested improvement(s), if they are within our board design standards and meet our product design requirements, we will flag these changes for our next board revision. *(Please note, that even if your suggestion is accepted, these changes may not be immediate. We may have to cycle through our current product inventory first.)*

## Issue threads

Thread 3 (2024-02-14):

Increase max voltage on silk and schematic / Allow 5V buck

nseidle, 2024-02-14:
Consider on the next rev:
* Input capacitor C4 is rated at 35V. Possibly change silk to a max of 24V or more.
* Add cap/IC voltage ratings to schematic
* Add a resistor and a NO jumper to allow selection between 3.3V and 5V output from the buck converter

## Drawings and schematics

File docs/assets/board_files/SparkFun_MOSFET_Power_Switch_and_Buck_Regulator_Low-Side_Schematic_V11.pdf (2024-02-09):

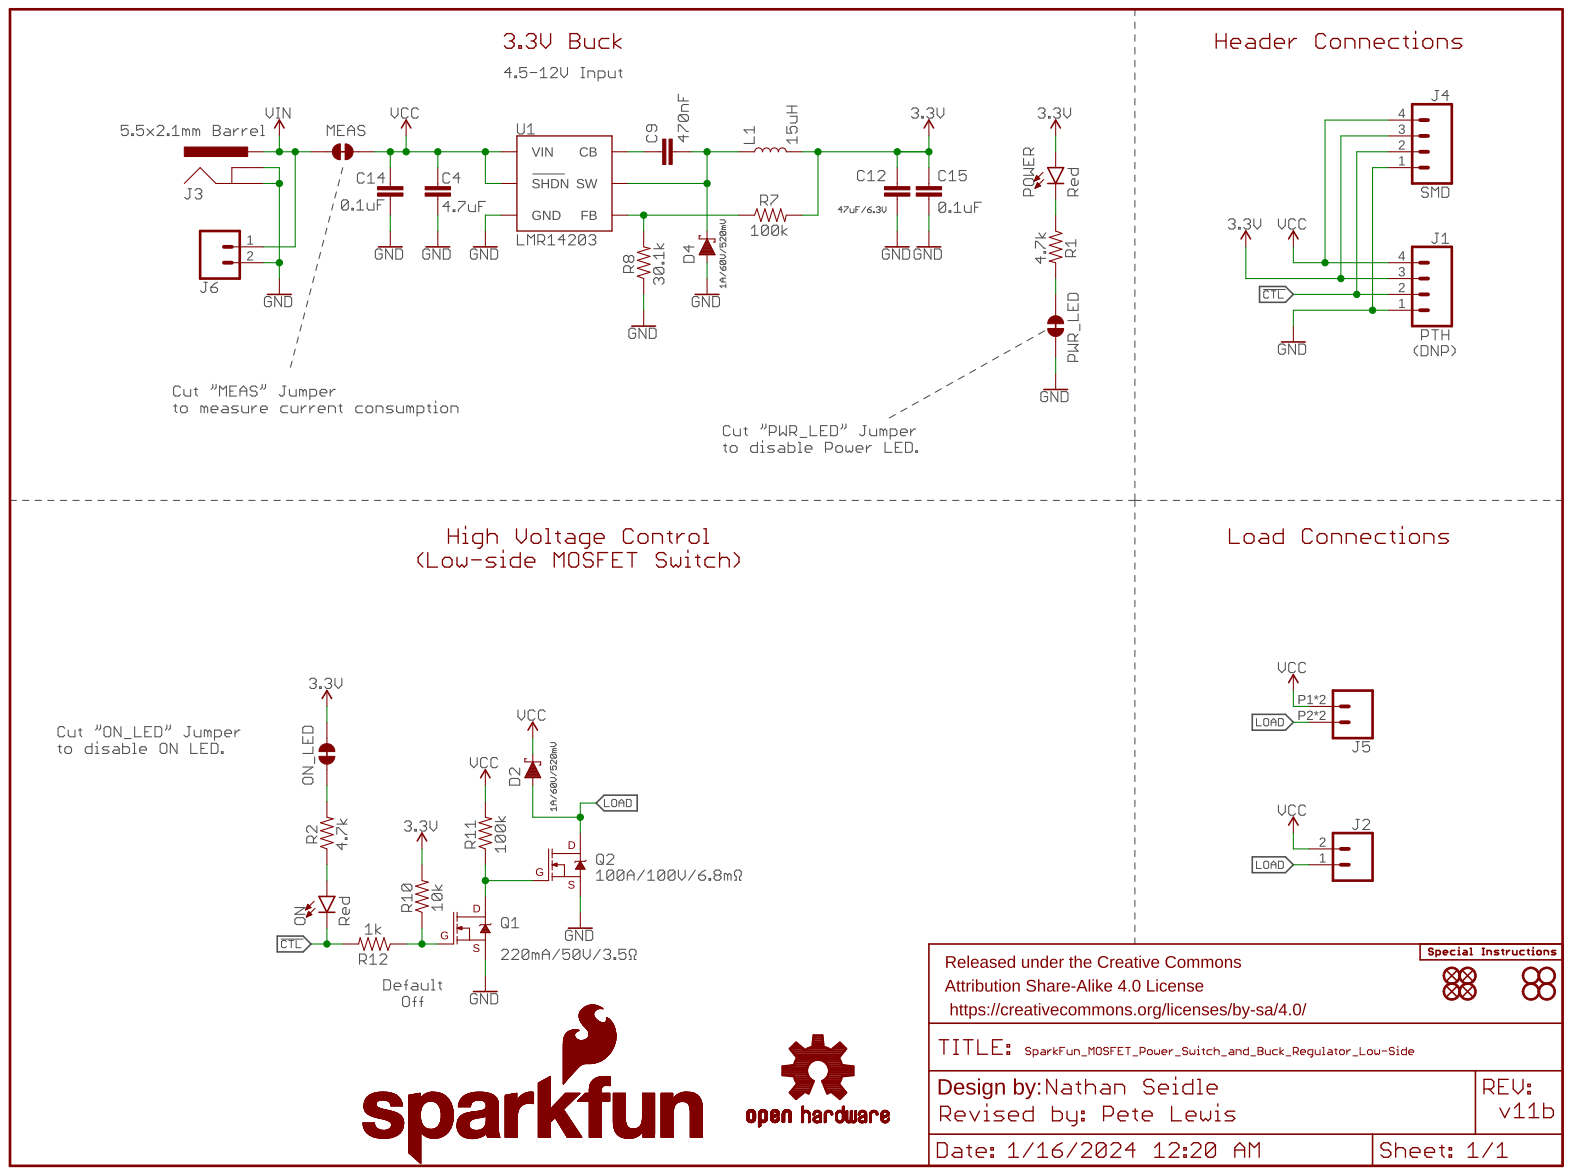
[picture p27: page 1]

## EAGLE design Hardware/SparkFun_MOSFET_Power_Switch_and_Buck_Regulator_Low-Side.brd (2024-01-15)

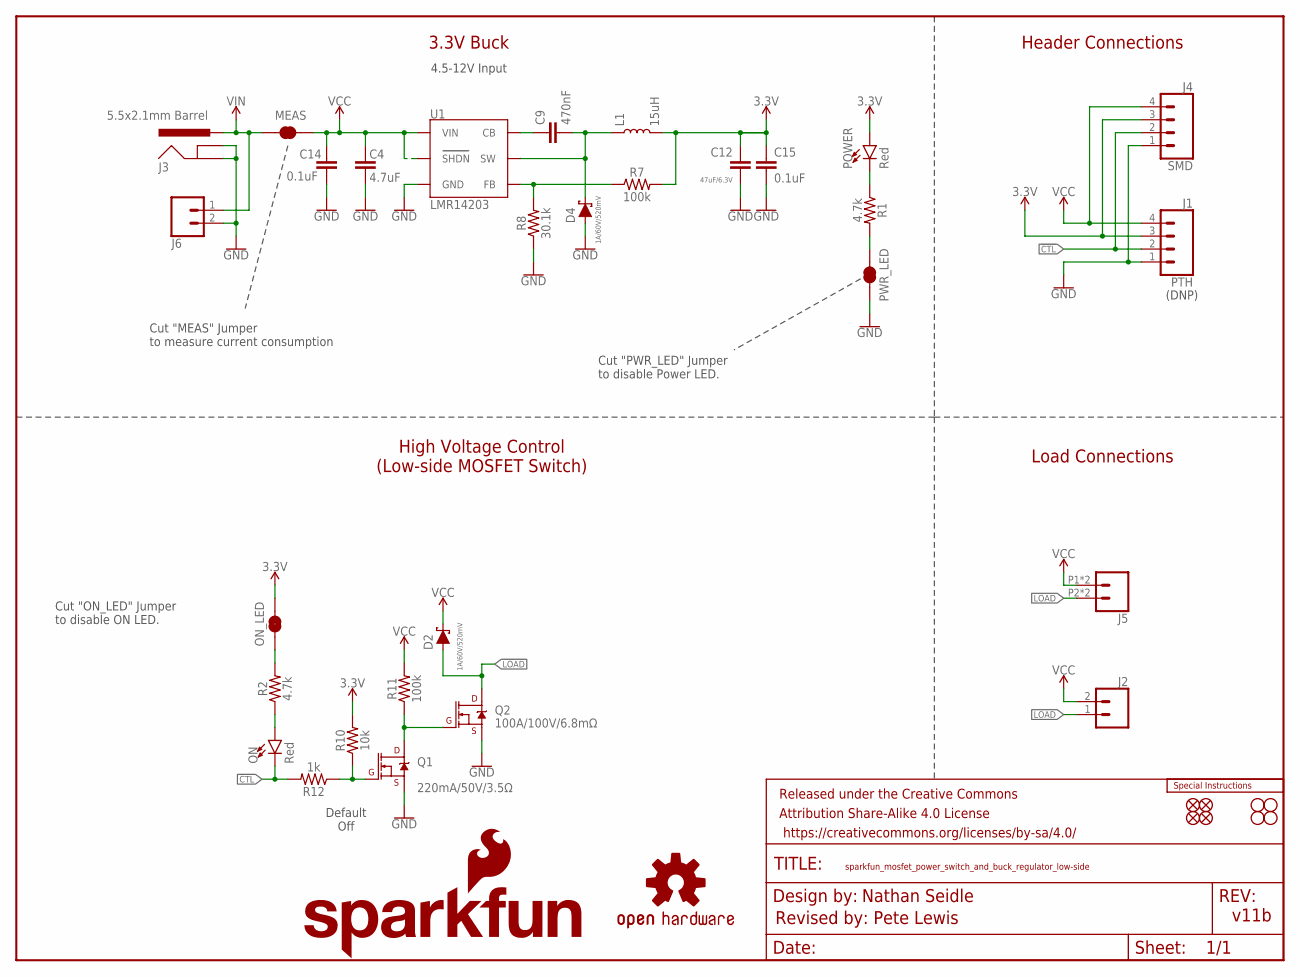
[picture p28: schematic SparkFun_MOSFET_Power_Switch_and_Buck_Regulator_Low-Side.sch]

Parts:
C4: 4.7uF; 0603
C9: 470nF; 0603
C12: 47uF/6.3V; 0805
C14, C15: 0.1uF; 0603
D2, D4: 1A/60V/520mV; DIODE-MICRO-SMP
FD1, FD2, FD3, FD4: FIDUCIALUFIDUCIAL; FIDUCIAL-MICRO
FRAME2: FRAME-LETTER; CREATIVE_COMMONS
H1, H2, H3, H4: STAND-OFF
J1: PTH; 1X04_NO_SILK
J2, J6: CONN_021X02_NO_SILK; 1X02_NO_SILK
J3: 5.5x2.1mm Barrel; POWER_JACK_SMD
J4: SMD; 1X04_SMD_VERTICAL_COMBO
J5: CONN_02SMALL_POKEHOME; 1X02_POKEHOME
L1: 15uH; INDUCTOR_LQH32
LOGO1: OSHW-LOGOM; OSHW-LOGO-M
LOGO2: SFE_LOGO_NAME_FLAME.2_INCH; SFE_LOGO_NAME_FLAME_.2
LOGO3: SPECIAL_INSTRUCTIONS-ORDERING; ORDERING_INSTRUCTIONS
MEAS: JUMPER-COMBO_2_NC_TRACE; COMBO-JUMPER_2_NC_TRACE
ON: Red; LED-0603
ON_LED: JUMPER-SMT_2_NC_TRACE_SILK; SMT-JUMPER_2_NC_TRACE_SILK
POWER: Red; LED-0603
PWR_LED: JUMPER-SMT_2_NC_TRACE_SILK; SMT-JUMPER_2_NC_TRACE_SILK
Q1: 220mA/50V/3.5Ω; SOT23-3
Q2: 100A/100V/6.8mΩ; TO-263/D2PAK
R1, R2: 4.7k; 0603
R7, R11: 100k; 0603
R8: 30.1k; 0603
R10: 10k; 0603
R12: 1k; 0603
U1: LMR14203; SOT23-6

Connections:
3.3V: C12.1, C15.1, J1.3, J4.3, L1.P$2 (2), ON_LED.2, POWER.A, R7.2, R10.2
!CTL: J1.2, J4.2, ON.C, R12.2
GND: C4.2, C12.2, C14.2, C15.2, D4.A, J1.1, J3.GND (GNDBREAK), J3.P$4 (GND), J4.1, J6.2, PWR_LED.1, Q1.2 (S), Q2.3 (S), R8.1, U1.2 (GND)
LOAD: D2.A, J2.1, J5.P2 (2), J5.P4 (2), Q2.2 (D)
unnamed: Q1.3 (D), Q2.1 (G), R11.1
unnamed: ON.A, R2.1
unnamed: POWER.C, R1.1
unnamed: R7.1, R8.2, U1.3 (FB)
unnamed: PWR_LED.2, R1.2
unnamed: ON_LED.1, R2.2
unnamed: C9.1, U1.1 (CB)
unnamed: Q1.1 (G), R10.1, R12.1
VCC: C4.1, C14.1, D2.C, J1.4, J2.2, J4.4, J5.P1 (1), J5.P3 (1), MEAS.2, MEAS.4 (2), R11.2, U1.4 (SHDN), U1.5 (VIN)
VIN: J3.VIN0 (PWR), J6.1, MEAS.1, MEAS.3 (1)
VSW: C9.2, D4.C, L1.P$1 (1), U1.6 (SW)

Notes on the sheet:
v11b
Default Off
Load Connections
High Voltage Control (Low-side MOSFET Switch)
3.3V Buck
4.5-12V Input
Nathan Seidle
Revised by: Pete Lewis
Header Connections
Cut "ON_LED" Jumper to disable ON LED.
Cut "PWR_LED" Jumper to disable Power LED.
(DNP)
Cut "MEAS" Jumper to measure current consumption

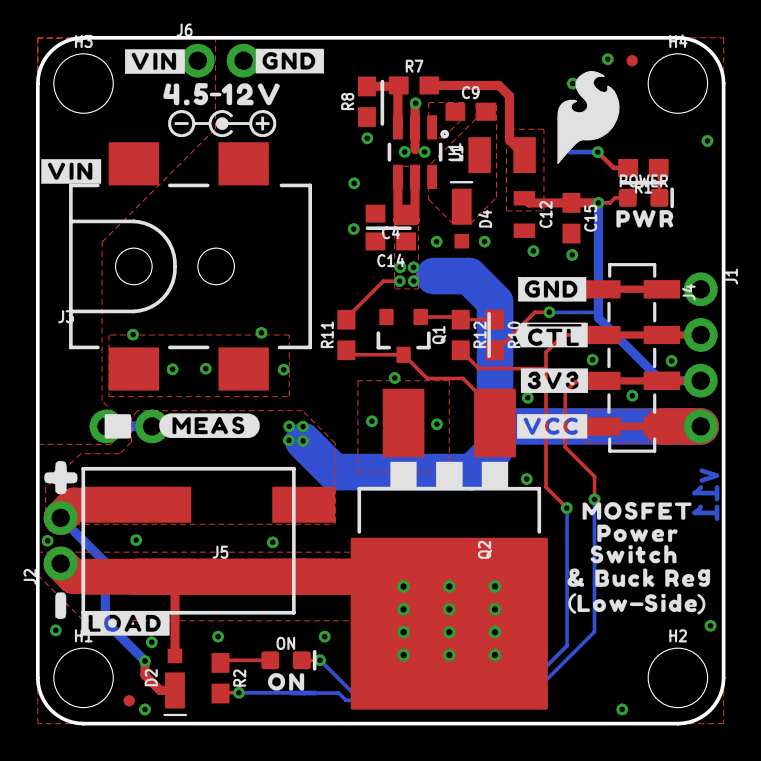
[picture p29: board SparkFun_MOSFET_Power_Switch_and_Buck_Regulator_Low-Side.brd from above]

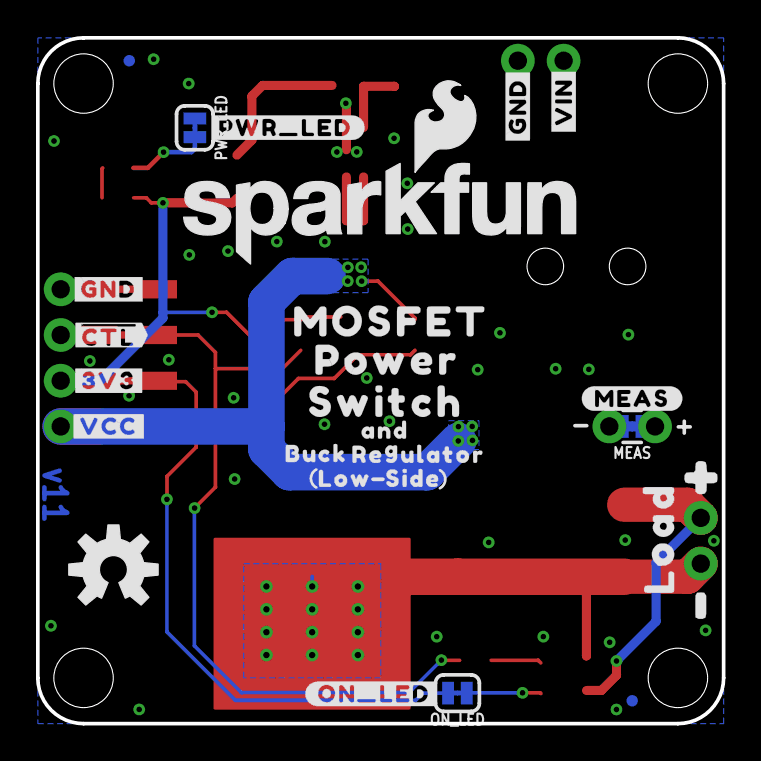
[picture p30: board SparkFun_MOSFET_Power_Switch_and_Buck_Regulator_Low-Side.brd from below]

Board: 2 copper layers, 38.1 x 38.1 mm, 83 parts (27 on the bottom side), 15 nets.

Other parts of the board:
U$1: #LOAD#7
U$2: MOSFET0
U$3, U$21, U$36: #VIN#8
U$4, U$6, U$12, U$37: #GND#0
U$8: SFE_LOGO_FLAME_.2
U$9: POWER1
U$10, U$20: #0
U$11, U$22: #1
U$13: SWITCH2
U$14, U$27: #3V3#3
U$15: #PWR_LED#11
U$16: #ON_LED#13
U$17, U$38: #MEAS#14
U$18: 4#5_12V5
U$19: LOAD0
U$23, U$43: LOW0
U$24: MOSFET_0
U$25: POWER_1
U$26: SWITCH_2
U$28: ##CTL##1
U$29: POLARITY_MARKING_CENTER_POSITIVE#JPG
U$30: ##CTL##2
U$31, U$32: #VCC#4
U$33, U$44: SIDE0
U$34: PWR9
U$35: ON10
U$39: BUCK5
U$40: REGULATOR6
U$41: #_BUCK_REG7
U$42: AND8

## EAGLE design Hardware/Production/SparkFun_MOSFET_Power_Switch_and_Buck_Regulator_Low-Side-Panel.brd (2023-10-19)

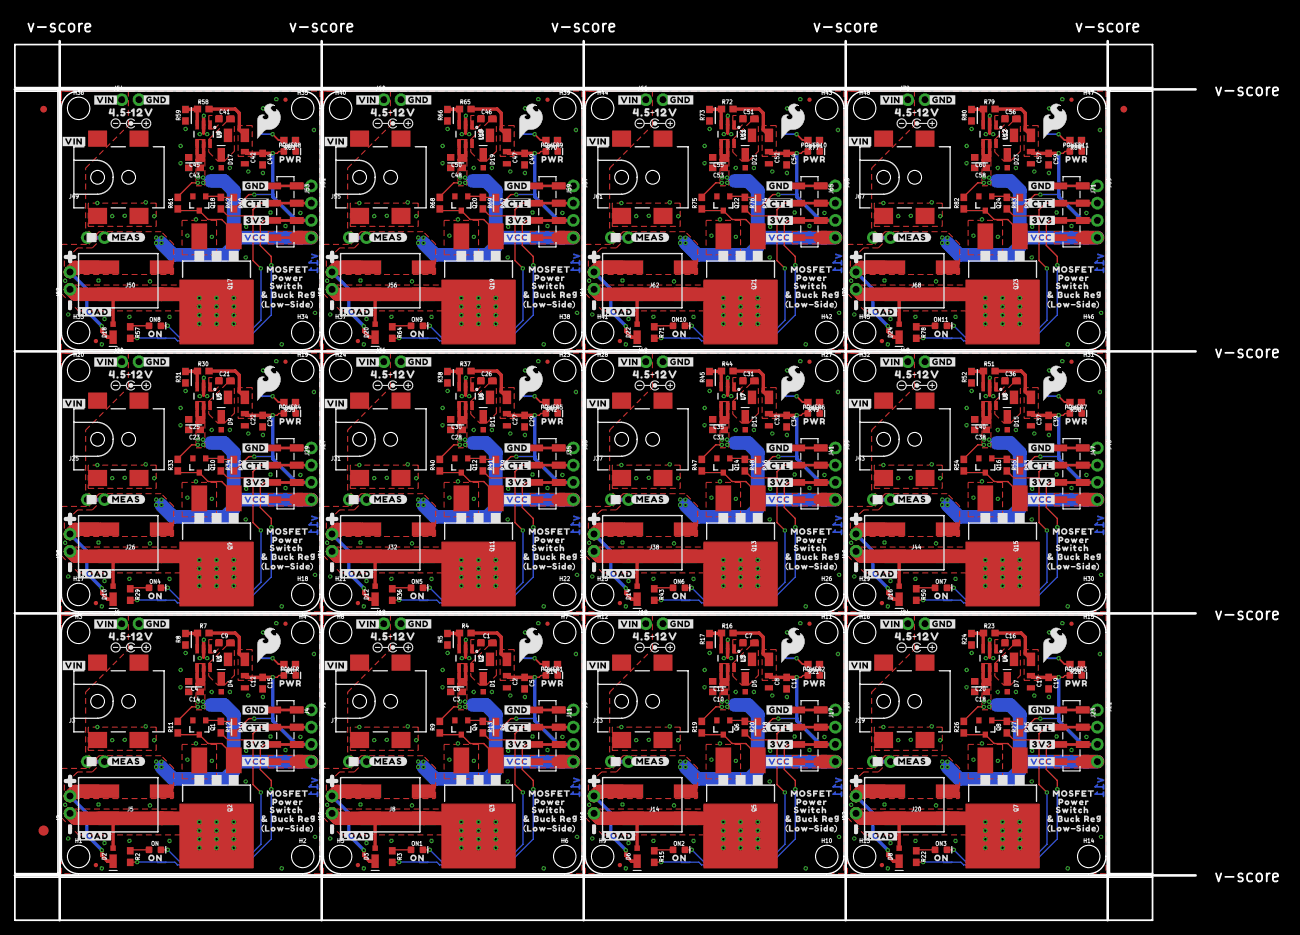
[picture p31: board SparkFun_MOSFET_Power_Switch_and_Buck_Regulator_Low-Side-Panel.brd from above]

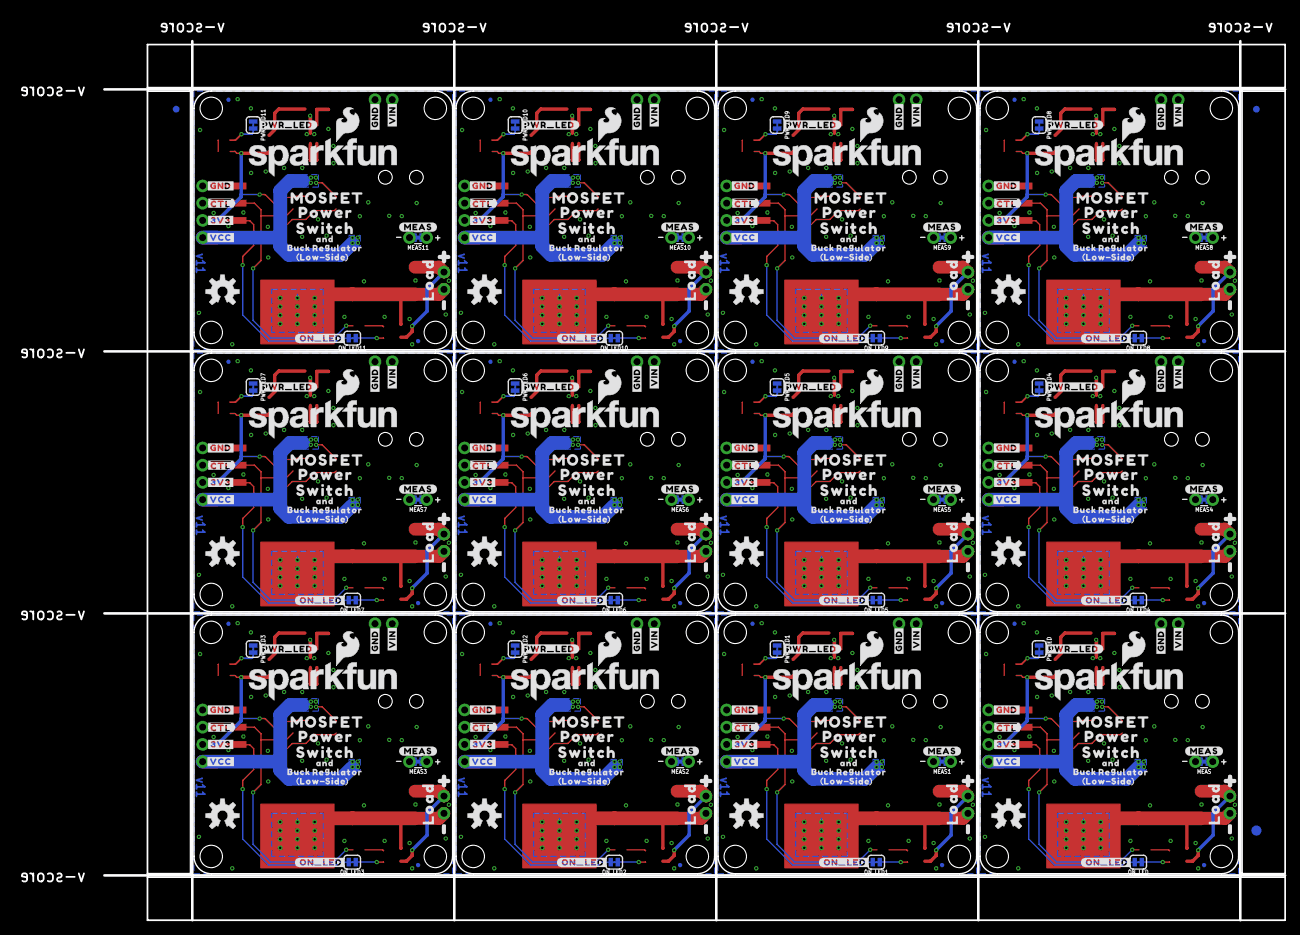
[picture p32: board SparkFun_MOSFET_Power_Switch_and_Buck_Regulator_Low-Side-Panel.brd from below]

Board: 2 copper layers, 174.0 x 129.5 mm, 978 parts (327 on the bottom side), 180 nets.

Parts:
C1, C7, C9, C16, C21, C26, C31, C36, C41, C46, C51, C56: 470nF; 0603
C2, C8, C12, C17, C22, C27, C32, C37, C42, C47, C52, C57: 47uF/6.3V; 0805
C3, C5, C10, C11, C14, C15, C18, C19, C23, C24, C28, C29, C33, C34, C38, C39, C43, C44, C48, C49, C53, C54, C58, C59: 0.1uF; 0603
C4, C6, C13, C20, C25, C30, C35, C40, C45, C50, C55, C60: 4.7uF; 0603
D1, D2, D3, D4, D5, D6, D7, D8, D9, D10, D11, D12, D13, D14, D15, D16, D17, D18, D19, D20, D21, D22, D23, D24: 1A/60V/520mV; DIODE-MICRO-SMP
E$1, E$2, E$3, E$4: FIDUCIAL-1X2
E$5, E$6: FIDUCIAL-1.5X3
FD1, FD2, FD3, FD4, FD5, FD6, FD7, FD8, FD9, FD10, FD11, FD12, FD13, FD14, FD15, FD16, FD17, FD18, FD19, FD20, FD21, FD22, FD23, FD24, FD25, FD26, FD27, FD28, FD29, FD30, FD31, FD32, FD33, FD34, FD35, FD36, FD37, FD38, FD39, FD40, FD41, FD42, FD43, FD44, FD45, FD46, FD47, FD48: FIDUCIALUFIDUCIAL; FIDUCIAL-MICRO
H1, H2, H3, H4, H5, H6, H7, H8, H9, H10, H11, H12, H13, H14, H15, H16, H17, H18, H19, H20, H21, H22, H23, H24, H25, H26, H27, H28, H29, H30, H31, H32, H33, H34, H35, H36, H37, H38, H39, H40, H41, H42, H43, H44, H45, H46, H47, H48: STAND-OFF
J1, J9, J15, J21, J27, J33, J39, J45, J51, J57, J63, J69: PTH; 1X04_NO_SILK
J2, J6, J10, J12, J16, J18, J22, J24, J28, J30, J34, J36, J40, J42, J46, J48, J52, J54, J58, J60, J64, J66, J70, J72: 1X02_NO_SILK
J3, J7, J13, J19, J25, J31, J37, J43, J49, J55, J61, J67: 5.5x2.1mm Barrel; POWER_JACK_SMD
J4, J11, J17, J23, J29, J35, J41, J47, J53, J59, J65, J71: SMD; 1X04_SMD_VERTICAL_COMBO
J5, J8, J14, J20, J26, J32, J38, J44, J50, J56, J62, J68: 1X02_POKEHOME
L1, L2, L3, L4, L5, L6, L7, L8, L9, L10, L11, L12: 15uH; INDUCTOR_LQH32
LOGO1, LOGO3, LOGO5, LOGO7, LOGO9, LOGO11, LOGO13, LOGO15, LOGO17, LOGO19, LOGO21, LOGO23: OSHW-LOGOM; OSHW-LOGO-M
LOGO2, LOGO4, LOGO6, LOGO8, LOGO10, LOGO12, LOGO14, LOGO16, LOGO18, LOGO20, LOGO22, LOGO24: SFE_LOGO_NAME_FLAME.2_INCH; SFE_LOGO_NAME_FLAME_.2
MEAS, MEAS1, MEAS2, MEAS3, MEAS4, MEAS5, MEAS6, MEAS7, MEAS8, MEAS9, MEAS10, MEAS11: JUMPER-COMBO_2_NC_TRACE; COMBO-JUMPER_2_NC_TRACE
ON, ON1, ON2, ON3, ON4, ON5, ON6, ON7, ON8, ON9, ON10, ON11: Red; LED-0603
ON_LED, ON_LED1, ON_LED2, ON_LED3, ON_LED4, ON_LED5, ON_LED6, ON_LED7, ON_LED8, ON_LED9, ON_LED10, ON_LED11: SMT-JUMPER_2_NC_TRACE_SILK
POWER, POWER1, POWER2, POWER3, POWER4, POWER5, POWER6, POWER7, POWER8, POWER9, POWER10, POWER11: Red; LED-0603
PWR_LED, PWR_LED1, PWR_LED2, PWR_LED3, PWR_LED4, PWR_LED5, PWR_LED6, PWR_LED7, PWR_LED8, PWR_LED9, PWR_LED10, PWR_LED11: SMT-JUMPER_2_NC_TRACE_SILK
Q1, Q4, Q6, Q8, Q10, Q12, Q14, Q16, Q18, Q20, Q22, Q24: 600mA/40V; SOT23-3
Q2, Q3, Q5, Q7, Q9, Q11, Q13, Q15, Q17, Q19, Q21, Q23: 100A/100V/6.8mΩ; TO-263/D2PAK
R1, R2, R3, R14, R15, R21, R22, R28, R29, R35, R36, R42, R43, R49, R50, R56, R57, R63, R64, R70, R71, R77, R78, R84: 4.7k; 0603
R4, R7, R16, R23, R30, R37, R44, R51, R58, R65, R72, R79: 100k; 0603
R5, R8, R17, R24, R31, R38, R45, R52, R59, R66, R73, R80: 30.1k; 0603
R6, R9, R10, R11, R18, R19, R25, R26, R32, R33, R39, R40, R46, R47, R53, R54, R60, R61, R67, R68, R74, R75, R81, R82: 10k; 0603
R12, R13, R20, R27, R34, R41, R48, R55, R62, R69, R76, R83: 1k; 0603
U1, U2, U3, U4, U5, U6, U7, U8, U9, U10, U11, U12: LMR14203; SOT23-6
U$1, U$63, U$105, U$147, U$189, U$231, U$273, U$315, U$357, U$399, U$441, U$483: #LOAD#7
U$2, U$49, U$91, U$133, U$175, U$217, U$259, U$301, U$343, U$385, U$427, U$469: MOSFET0
U$3, U$21, U$36, U$64, U$71, U$75, U$106, U$113, U$117, U$148, U$155, U$159, U$190, U$197, U$201, U$232, U$239, U$243, U$274, U$281, U$285, U$316, U$323, U$327, U$358, U$365, U$369, U$400, U$407, U$411, U$442, U$449, U$453, U$484, U$491, U$495: #VIN#8
U$4, U$6, U$12, U$37, U$55, U$56, U$72, U$74, U$97, U$98, U$114, U$116, U$139, U$140, U$156, U$158, U$181, U$182, U$198, U$200, U$223, U$224, U$240, U$242, U$265, U$266, U$282, U$284, U$307, U$308, U$324, U$326, U$349, U$350, U$366, U$368, U$391, U$392, U$408, U$410, U$433, U$434, U$450, U$452, U$475, U$476, U$492, U$494: #GND#0
U$5, U$29, U$85, U$127, U$169, U$211, U$253, U$295, U$337, U$379, U$421, U$463: POLARITY_MARKING_CENTER_POSITIVE#JPG
U$7, U$10, U$20, U$47, U$86, U$89, U$128, U$131, U$170, U$173, U$212, U$215, U$254, U$257, U$296, U$299, U$338, U$341, U$380, U$383, U$422, U$425, U$464, U$467: #0
U$8, U$65, U$107, U$149, U$191, U$233, U$275, U$317, U$359, U$401, U$443, U$485: SFE_LOGO_FLAME_.2
U$9, U$50, U$92, U$134, U$176, U$218, U$260, U$302, U$344, U$386, U$428, U$470: POWER1
U$11, U$22, U$45, U$48, U$87, U$90, U$129, U$132, U$171, U$174, U$213, U$216, U$255, U$258, U$297, U$300, U$339, U$342, U$381, U$384, U$423, U$426, U$465, U$468: #1
U$13, U$51, U$93, U$135, U$177, U$219, U$261, U$303, U$345, U$387, U$429, U$471: SWITCH2
U$14, U$27, U$59, U$60, U$101, U$102, U$143, U$144, U$185, U$186, U$227, U$228, U$269, U$270, U$311, U$312, U$353, U$354, U$395, U$396, U$437, U$438, U$479, U$480: #3V3#3
U$15, U$66, U$108, U$150, U$192, U$234, U$276, U$318, U$360, U$402, U$444, U$486: #PWR_LED#11
U$16, U$67, U$109, U$151, U$193, U$235, U$277, U$319, U$361, U$403, U$445, U$487: #ON_LED#13
U$17, U$38, U$68, U$76, U$110, U$118, U$152, U$160, U$194, U$202, U$236, U$244, U$278, U$286, U$320, U$328, U$362, U$370, U$404, U$412, U$446, U$454, U$488, U$496: #MEAS#14
U$18, U$73, U$115, U$157, U$199, U$241, U$283, U$325, U$367, U$409, U$451, U$493: 4#5_12V5
U$19, U$46, U$88, U$130, U$172, U$214, U$256, U$298, U$340, U$382, U$424, U$466: LOAD0
U$23, U$43, U$69, U$81, U$111, U$123, U$153, U$165, U$195, U$207, U$237, U$249, U$279, U$291, U$321, U$333, U$363, U$375, U$405, U$417, U$447, U$459, U$489, U$501: LOW0
U$24, U$52, U$94, U$136, U$178, U$220, U$262, U$304, U$346, U$388, U$430, U$472: MOSFET_0
U$25, U$53, U$95, U$137, U$179, U$221, U$263, U$305, U$347, U$389, U$431, U$473: POWER_1
U$26, U$54, U$96, U$138, U$180, U$222, U$264, U$306, U$348, U$390, U$432, U$474: SWITCH_2
U$28, U$57, U$99, U$141, U$183, U$225, U$267, U$309, U$351, U$393, U$435, U$477: ##CTL##1
U$30, U$58, U$100, U$142, U$184, U$226, U$268, U$310, U$352, U$394, U$436, U$478: ##CTL##2
U$31, U$32, U$61, U$62, U$103, U$104, U$145, U$146, U$187, U$188, U$229, U$230, U$271, U$272, U$313, U$314, U$355, U$356, U$397, U$398, U$439, U$440, U$481, U$482: #VCC#4
U$33, U$44, U$70, U$82, U$112, U$124, U$154, U$166, U$196, U$208, U$238, U$250, U$280, U$292, U$322, U$334, U$364, U$376, U$406, U$418, U$448, U$460, U$490, U$502: SIDE0
U$34, U$83, U$125, U$167, U$209, U$251, U$293, U$335, U$377, U$419, U$461, U$503: PWR9
U$35, U$84, U$126, U$168, U$210, U$252, U$294, U$336, U$378, U$420, U$462, U$504: ON10
U$39, U$77, U$119, U$161, U$203, U$245, U$287, U$329, U$371, U$413, U$455, U$497: BUCK5
U$40, U$78, U$120, U$162, U$204, U$246, U$288, U$330, U$372, U$414, U$456, U$498: REGULATOR6
U$41, U$79, U$121, U$163, U$205, U$247, U$289, U$331, U$373, U$415, U$457, U$499: #_BUCK_REG7
U$42, U$80, U$122, U$164, U$206, U$248, U$290, U$332, U$374, U$416, U$458, U$500: AND8

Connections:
3.3V: C12.1, C15.1, J1.3, J4.3, L1.P$2, ON_LED.2, POWER.A, R7.2, R10.2
3.3V1: C2.1, C5.1, J9.3, J11.3, L2.P$2, ON_LED1.2, POWER1.A, R4.2, R6.2
3.3V2: C8.1, C11.1, J15.3, J17.3, L3.P$2, ON_LED2.2, POWER2.A, R16.2, R18.2
3.3V3: C17.1, C19.1, J21.3, J23.3, L4.P$2, ON_LED3.2, POWER3.A, R23.2, R25.2
3.3V4: C22.1, C24.1, J27.3, J29.3, L5.P$2, ON_LED4.2, POWER4.A, R30.2, R32.2
3.3V5: C27.1, C29.1, J33.3, J35.3, L6.P$2, ON_LED5.2, POWER5.A, R37.2, R39.2
3.3V6: C32.1, C34.1, J39.3, J41.3, L7.P$2, ON_LED6.2, POWER6.A, R44.2, R46.2
3.3V7: C37.1, C39.1, J45.3, J47.3, L8.P$2, ON_LED7.2, POWER7.A, R51.2, R53.2
3.3V8: C42.1, C44.1, J51.3, J53.3, L9.P$2, ON_LED8.2, POWER8.A, R58.2, R60.2
3.3V9: C47.1, C49.1, J57.3, J59.3, L10.P$2, ON_LED9.2, POWER9.A, R65.2, R67.2
3.3V10: C52.1, C54.1, J63.3, J65.3, L11.P$2, ON_LED10.2, POWER10.A, R72.2, R74.2
3.3V11: C57.1, C59.1, J69.3, J71.3, L12.P$2, ON_LED11.2, POWER11.A, R79.2, R81.2
!CTL: J1.2, J4.2, ON.C, R12.2
!CTL1: J9.2, J11.2, ON1.C, R13.2
!CTL2: J15.2, J17.2, ON2.C, R20.2
!CTL3: J21.2, J23.2, ON3.C, R27.2
!CTL4: J27.2, J29.2, ON4.C, R34.2
!CTL5: J33.2, J35.2, ON5.C, R41.2
!CTL6: J39.2, J41.2, ON6.C, R48.2
!CTL7: J45.2, J47.2, ON7.C, R55.2
!CTL8: J51.2, J53.2, ON8.C, R62.2
!CTL9: J57.2, J59.2, ON9.C, R69.2
!CTL10: J63.2, J65.2, ON10.C, R76.2
!CTL11: J69.2, J71.2, ON11.C, R83.2
GND: C4.2, C12.2, C14.2, C15.2, D4.A, J1.1, J3.GND, J3.P$4, J4.1, J6.2, PWR_LED.1, Q1.2, Q2.3, R8.1, U1.2
GND1: C2.2, C3.2, C5.2, C6.2, D1.A, J7.GND, J7.P$4, J9.1, J11.1, J12.2, PWR_LED1.1, Q3.3, Q4.2, R5.1, U2.2
GND2: C8.2, C10.2, C11.2, C13.2, D5.A, J13.GND, J13.P$4, J15.1, J17.1, J18.2, PWR_LED2.1, Q5.3, Q6.2, R17.1, U3.2
GND3: C17.2, C18.2, C19.2, C20.2, D7.A, J19.GND, J19.P$4, J21.1, J23.1, J24.2, PWR_LED3.1, Q7.3, Q8.2, R24.1, U4.2
GND4: C22.2, C23.2, C24.2, C25.2, D9.A, J25.GND, J25.P$4, J27.1, J29.1, J30.2, PWR_LED4.1, Q9.3, Q10.2, R31.1, U5.2
GND5: C27.2, C28.2, C29.2, C30.2, D11.A, J31.GND, J31.P$4, J33.1, J35.1, J36.2, PWR_LED5.1, Q11.3, Q12.2, R38.1, U6.2
GND6: C32.2, C33.2, C34.2, C35.2, D13.A, J37.GND, J37.P$4, J39.1, J41.1, J42.2, PWR_LED6.1, Q13.3, Q14.2, R45.1, U7.2
GND7: C37.2, C38.2, C39.2, C40.2, D15.A, J43.GND, J43.P$4, J45.1, J47.1, J48.2, PWR_LED7.1, Q15.3, Q16.2, R52.1, U8.2
GND8: C42.2, C43.2, C44.2, C45.2, D17.A, J49.GND, J49.P$4, J51.1, J53.1, J54.2, PWR_LED8.1, Q17.3, Q18.2, R59.1, U9.2
GND9: C47.2, C48.2, C49.2, C50.2, D19.A, J55.GND, J55.P$4, J57.1, J59.1, J60.2, PWR_LED9.1, Q19.3, Q20.2, R66.1, U10.2
GND10: C52.2, C53.2, C54.2, C55.2, D21.A, J61.GND, J61.P$4, J63.1, J65.1, J66.2, PWR_LED10.1, Q21.3, Q22.2, R73.1, U11.2
GND11: C57.2, C58.2, C59.2, C60.2, D23.A, J67.GND, J67.P$4, J69.1, J71.1, J72.2, PWR_LED11.1, Q23.3, Q24.2, R80.1, U12.2
LOAD: D2.A, J2.1, J5.P2, J5.P4, Q2.2
LOAD1: D3.A, J8.P2, J8.P4, J10.1, Q3.2
LOAD2: D6.A, J14.P2, J14.P4, J16.1, Q5.2
LOAD3: D8.A, J20.P2, J20.P4, J22.1, Q7.2
LOAD4: D10.A, J26.P2, J26.P4, J28.1, Q9.2
LOAD5: D12.A, J32.P2, J32.P4, J34.1, Q11.2
LOAD6: D14.A, J38.P2, J38.P4, J40.1, Q13.2
LOAD7: D16.A, J44.P2, J44.P4, J46.1, Q15.2
LOAD8: D18.A, J50.P2, J50.P4, J52.1, Q17.2
LOAD9: D20.A, J56.P2, J56.P4, J58.1, Q19.2
LOAD10: D22.A, J62.P2, J62.P4, J64.1, Q21.2
LOAD11: D24.A, J68.P2, J68.P4, J70.1, Q23.2
unnamed: Q1.3, Q2.1, R11.1
unnamed: ON.A, R2.1
unnamed: POWER.C, R1.1
unnamed: ON1.A, R3.1
unnamed: R7.1, R8.2, U1.3
unnamed: PWR_LED.2, R1.2
unnamed: ON_LED.1, R2.2
unnamed: R4.1, R5.2, U2.3
unnamed: C1.1, U2.1
unnamed: C9.1, U1.1
unnamed: Q3.1, Q4.3, R9.1
unnamed: Q1.1, R10.1, R12.1
unnamed: Q4.1, R6.1, R13.1
unnamed: POWER1.C, R14.1
unnamed: PWR_LED1.2, R14.2
unnamed: ON_LED1.1, R3.2
unnamed: ON2.A, R15.1
unnamed: R16.1, R17.2, U3.3
unnamed: C7.1, U3.1
unnamed: Q5.1, Q6.3, R19.1
unnamed: Q6.1, R18.1, R20.1
unnamed: POWER2.C, R21.1
unnamed: PWR_LED2.2, R21.2
unnamed: ON_LED2.1, R15.2
unnamed: ON3.A, R22.1
unnamed: R23.1, R24.2, U4.3
unnamed: C16.1, U4.1
unnamed: Q7.1, Q8.3, R26.1
unnamed: Q8.1, R25.1, R27.1
unnamed: POWER3.C, R28.1
unnamed: PWR_LED3.2, R28.2
unnamed: ON_LED3.1, R22.2
unnamed: ON4.A, R29.1
unnamed: R30.1, R31.2, U5.3
unnamed: C21.1, U5.1
unnamed: Q9.1, Q10.3, R33.1
unnamed: Q10.1, R32.1, R34.1
unnamed: POWER4.C, R35.1
unnamed: PWR_LED4.2, R35.2
unnamed: ON_LED4.1, R29.2
unnamed: ON5.A, R36.1
unnamed: R37.1, R38.2, U6.3
unnamed: C26.1, U6.1
unnamed: Q11.1, Q12.3, R40.1
unnamed: Q12.1, R39.1, R41.1
unnamed: POWER5.C, R42.1
unnamed: PWR_LED5.2, R42.2
unnamed: ON_LED5.1, R36.2
unnamed: ON6.A, R43.1
unnamed: R44.1, R45.2, U7.3
unnamed: C31.1, U7.1
unnamed: Q13.1, Q14.3, R47.1
unnamed: Q14.1, R46.1, R48.1
unnamed: POWER6.C, R49.1
unnamed: PWR_LED6.2, R49.2
unnamed: ON_LED6.1, R43.2
unnamed: ON7.A, R50.1
unnamed: R51.1, R52.2, U8.3
unnamed: C36.1, U8.1
unnamed: Q15.1, Q16.3, R54.1
unnamed: Q16.1, R53.1, R55.1
unnamed: POWER7.C, R56.1
unnamed: PWR_LED7.2, R56.2
unnamed: ON_LED7.1, R50.2
unnamed: ON8.A, R57.1
unnamed: R58.1, R59.2, U9.3
unnamed: C41.1, U9.1
unnamed: Q17.1, Q18.3, R61.1
unnamed: Q18.1, R60.1, R62.1
unnamed: POWER8.C, R63.1
unnamed: PWR_LED8.2, R63.2
unnamed: ON_LED8.1, R57.2
unnamed: ON9.A, R64.1
unnamed: R65.1, R66.2, U10.3
unnamed: C46.1, U10.1
unnamed: Q19.1, Q20.3, R68.1
unnamed: Q20.1, R67.1, R69.1
unnamed: POWER9.C, R70.1
unnamed: PWR_LED9.2, R70.2
unnamed: ON_LED9.1, R64.2
unnamed: ON10.A, R71.1
unnamed: R72.1, R73.2, U11.3
unnamed: C51.1, U11.1
unnamed: Q21.1, Q22.3, R75.1
unnamed: Q22.1, R74.1, R76.1
unnamed: POWER10.C, R77.1
unnamed: PWR_LED10.2, R77.2
unnamed: ON_LED10.1, R71.2
unnamed: ON11.A, R78.1
unnamed: R79.1, R80.2, U12.3
unnamed: C56.1, U12.1
unnamed: Q23.1, Q24.3, R82.1
unnamed: Q24.1, R81.1, R83.1
unnamed: POWER11.C, R84.1
unnamed: PWR_LED11.2, R84.2
unnamed: ON_LED11.1, R78.2
VCC: C4.1, C14.1, D2.C, J1.4, J2.2, J4.4, J5.P1, J5.P3, MEAS.2, MEAS.4, R11.2, U1.4, U1.5
VCC1: C3.1, C6.1, D3.C, J8.P1, J8.P3, J9.4, J10.2, J11.4, MEAS1.2, MEAS1.4, R9.2, U2.4, U2.5
VCC2: C10.1, C13.1, D6.C, J14.P1, J14.P3, J15.4, J16.2, J17.4, MEAS2.2, MEAS2.4, R19.2, U3.4, U3.5
VCC3: C18.1, C20.1, D8.C, J20.P1, J20.P3, J21.4, J22.2, J23.4, MEAS3.2, MEAS3.4, R26.2, U4.4, U4.5
VCC4: C23.1, C25.1, D10.C, J26.P1, J26.P3, J27.4, J28.2, J29.4, MEAS4.2, MEAS4.4, R33.2, U5.4, U5.5
VCC5: C28.1, C30.1, D12.C, J32.P1, J32.P3, J33.4, J34.2, J35.4, MEAS5.2, MEAS5.4, R40.2, U6.4, U6.5
VCC6: C33.1, C35.1, D14.C, J38.P1, J38.P3, J39.4, J40.2, J41.4, MEAS6.2, MEAS6.4, R47.2, U7.4, U7.5
VCC7: C38.1, C40.1, D16.C, J44.P1, J44.P3, J45.4, J46.2, J47.4, MEAS7.2, MEAS7.4, R54.2, U8.4, U8.5
VCC8: C43.1, C45.1, D18.C, J50.P1, J50.P3, J51.4, J52.2, J53.4, MEAS8.2, MEAS8.4, R61.2, U9.4, U9.5
VCC9: C48.1, C50.1, D20.C, J56.P1, J56.P3, J57.4, J58.2, J59.4, MEAS9.2, MEAS9.4, R68.2, U10.4, U10.5
VCC10: C53.1, C55.1, D22.C, J62.P1, J62.P3, J63.4, J64.2, J65.4, MEAS10.2, MEAS10.4, R75.2, U11.4, U11.5
VCC11: C58.1, C60.1, D24.C, J68.P1, J68.P3, J69.4, J70.2, J71.4, MEAS11.2, MEAS11.4, R82.2, U12.4, U12.5
VIN: J3.VIN0, J6.1, MEAS.1, MEAS.3
VIN1: J7.VIN0, J12.1, MEAS1.1, MEAS1.3
VIN2: J13.VIN0, J18.1, MEAS2.1, MEAS2.3
VIN3: J19.VIN0, J24.1, MEAS3.1, MEAS3.3
VIN4: J25.VIN0, J30.1, MEAS4.1, MEAS4.3
VIN5: J31.VIN0, J36.1, MEAS5.1, MEAS5.3
VIN6: J37.VIN0, J42.1, MEAS6.1, MEAS6.3
VIN7: J43.VIN0, J48.1, MEAS7.1, MEAS7.3
VIN8: J49.VIN0, J54.1, MEAS8.1, MEAS8.3
VIN9: J55.VIN0, J60.1, MEAS9.1, MEAS9.3
VIN10: J61.VIN0, J66.1, MEAS10.1, MEAS10.3
VIN11: J67.VIN0, J72.1, MEAS11.1, MEAS11.3
VSW: C9.2, D4.C, L1.P$1, U1.6
VSW1: C1.2, D1.C, L2.P$1, U2.6
VSW2: C7.2, D5.C, L3.P$1, U3.6
VSW3: C16.2, D7.C, L4.P$1, U4.6
VSW4: C21.2, D9.C, L5.P$1, U5.6
VSW5: C26.2, D11.C, L6.P$1, U6.6
VSW6: C31.2, D13.C, L7.P$1, U7.6
VSW7: C36.2, D15.C, L8.P$1, U8.6
VSW8: C41.2, D17.C, L9.P$1, U9.6
VSW9: C46.2, D19.C, L10.P$1, U10.6
VSW10: C51.2, D21.C, L11.P$1, U11.6
VSW11: C56.2, D23.C, L12.P$1, U12.6

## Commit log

2023-10-09 Original SparkX hardware files (v10)
    [SparkFun_MOSFET_Power_Switch.brd, SparkFun_MOSFET_Power_Switch.sch]
2023-10-12 add 4-pin female header
    -added SMD vertical 4-pin header to allow solderless connection access to the CTRL line and more.
    -Added jumpers to kill power and on LEDs
    -updated silk to inverted buzzard style
    -changed logo to SFE
    -updated measures.
    [SparkFun_MOSFET_Power_Switch.brd, SparkFun_MOSFET_Power_Switch.sch]
2023-10-13 Buck reg routing
    -optimized buck reg routing
    -added PTH header for VIN/GND
    -added "low-side" to silk name top and bottom
    [SparkFun_MOSFET_Power_Switch.brd, SparkFun_MOSFET_Power_Switch.sch]
2023-10-13 MOSFET datasheet
2023-10-13 updated to new KB red resistor
    -updated red led and limiting resistor
    [SparkFun_MOSFET_Power_Switch.brd, SparkFun_MOSFET_Power_Switch.sch]
2023-10-13 Re-routed Flyback Diode circuit
    [SparkFun_MOSFET_Power_Switch.brd]
2023-10-17 Group Review mods round one
    -Powered ON LED from 3.3V and controlled via CTL net.
    -Moved GND/VIN PTH headers away from under the barrel jack for easier access
    -routed some of load path with polygons to avoid sharp 90 degree turns in traces
    -moved MEAS jumper to allow direct GND pour path from MOSFET to Barrel jack GND pads
    -added "+" and "-" silk to MEAS jumper PTH header
    -enlarged board to 1.5" square shape
    -spaced out components near BJT for better DFM
    -nudged some vias to avoid silk
    -corrected voltage input range to "4.5-12V".
    -added ordering instructions
    -Larger logos
    -added and updated measures
    [SparkFun_MOSFET_Power_Switch.brd, SparkFun_MOSFET_Power_Switch.sch]
2023-10-17 BOM consolidation
    -made the two 0.1uF caps the same one (100V).
    -Enlarged LOAD net trace/connection with polygon.
    [SparkFun_MOSFET_Power_Switch.brd, SparkFun_MOSFET_Power_Switch.sch]
2023-10-18 renaming files to match product name
    [SparkFun_MOSFET_Power_Switch_and_Buck_Regulator_Low-Side.brd, SparkFun_MOSFET_Power_Switch_and_Buck_Regulator_Low-Side.sch]
2023-10-18 Update silk to match product name
    [SparkFun_MOSFET_Power_Switch_and_Buck_Regulator_Low-Side.brd]
2023-10-18 sch cleanup
    -moved INPUT range to just below the “3.3V Buck” section title.
    [SparkFun_MOSFET_Power_Switch_and_Buck_Regulator_Low-Side.sch]
2023-10-18 Added D1 Zener
    -Added D1 to clamp spike on VCC and protect U1 and C4
    [SparkFun_MOSFET_Power_Switch_and_Buck_Regulator_Low-Side.brd, SparkFun_MOSFET_Power_Switch_and_Buck_Regulator_Low-Side.sch]
2023-10-18 approved DRC overlap errors on jumpers
    [SparkFun_MOSFET_Power_Switch_and_Buck_Regulator_Low-Side.brd]
2023-10-18 text overlap in sch
    [SparkFun_MOSFET_Power_Switch_and_Buck_Regulator_Low-Side.brd, SparkFun_MOSFET_Power_Switch_and_Buck_Regulator_Low-Side.sch]
2023-10-18 group review final changes
    -moved 4-pin header north 0.05inch to get all headers on same grid for perf board plug in ability.
    -MEAS moved to on grid.
    -upped material quality to TG155
    -LED labels to text only style silk
    -added exposed copper for heat sink under the MOSFET
    [SparkFun_MOSFET_Power_Switch_and_Buck_Regulator_Low-Side.brd]
2023-10-19 Removed D1 Zener
    [SparkFun_MOSFET_Power_Switch_and_Buck_Regulator_Low-Side.brd, SparkFun_MOSFET_Power_Switch_and_Buck_Regulator_Low-Side.sch]
2023-10-19 checklist run eng
    -sch tightening and cleanup
    -nudged some vias to avoid cutting silk in bottom logo
    [SparkFun_MOSFET_Power_Switch_and_Buck_Regulator_Low-Side.brd, SparkFun_MOSFET_Power_Switch_and_Buck_Regulator_Low-Side.sch]
2023-10-19 production panel and gerbers v11
    [SparkFun_MOSFET_Power_Switch_and_Buck_Regulator_Low-Side-Panel.GBL, SparkFun_MOSFET_Power_Switch_and_Buck_Regulator_Low-Side-Panel.GBO, SparkFun_MOSFET_Power_S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]
2023-10-23 Fix minor spelling error in schematic's note. =)
    [SparkFun_MOSFET_Power_Switch_and_Buck_Regulator_Low-Side.sch]
2024-01-15 updated Q1 and R11
    -Q1 is now an NCH MOSFET
    -R11 is increased to 100K to save power when things are turned off.
    [SparkFun_MOSFET_Power_Switch_and_Buck_Regulator_Low-Side.brd, SparkFun_MOSFET_Power_Switch_and_Buck_Regulator_Low-Side.sch]

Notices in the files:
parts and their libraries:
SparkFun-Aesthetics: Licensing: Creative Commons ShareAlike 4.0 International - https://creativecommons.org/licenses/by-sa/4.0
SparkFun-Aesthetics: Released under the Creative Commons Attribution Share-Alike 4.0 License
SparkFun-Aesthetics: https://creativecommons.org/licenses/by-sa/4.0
